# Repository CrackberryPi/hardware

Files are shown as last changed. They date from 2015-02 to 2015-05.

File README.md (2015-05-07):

# Crackberry Pi hardware

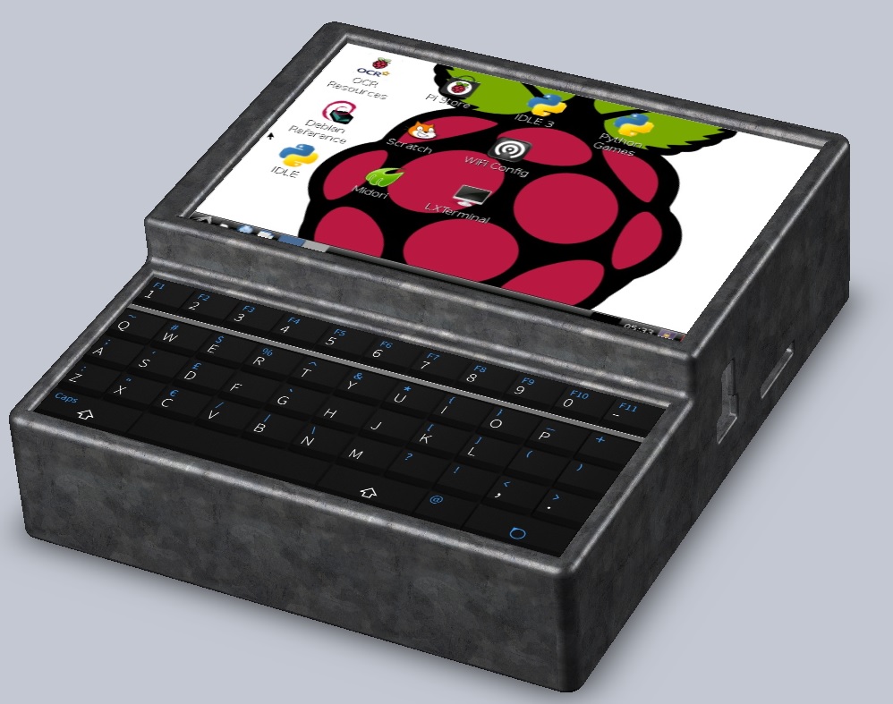
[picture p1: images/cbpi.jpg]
render terrible render


## The plan

The idea is to develop a complete and usable handheld system based on the Raspberry Pi. For this purpose we plan to create a PCB that will provide a small touch screen, a tiny keyboard and some other features. Together with a custom enclosure and a Lithium Ion battery this would form a complete handheld system.

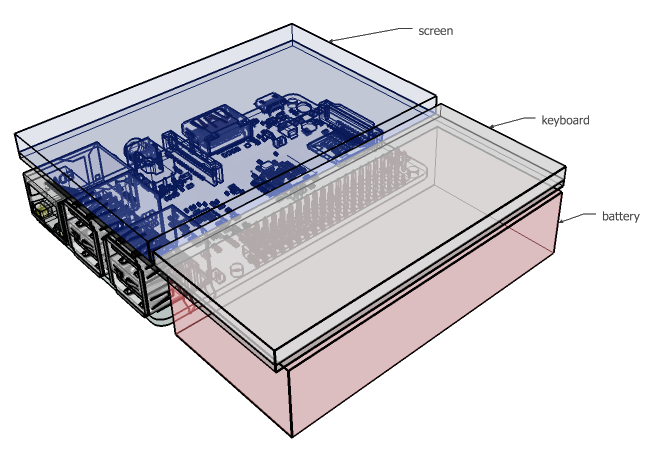
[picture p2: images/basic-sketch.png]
basic sketch


## Progress

####Up and running:

RTC -- [code](http://www.100randomtasks.com/raspberry-pi-rtc)

Random generator -- Lots of noise, lots of 1s and 0s

IR RX -- Using LIRC able to record IR

####Tested but does not work:

Screen -- some wiring issues

Touch controller -- does not show up in i2cdetect

IR TX

####Not yet tested

Keyboard controller

FM

Battery power and charging

EEPROM

## Hardware functionality

### Screen

3.5" 480x320 resistive touch screen. A number of parties sell boards to interface such screens to the Rasberry Pi already. The screens are generally more or less exactly the same size as the Raspberry Pi.

The preliminary candidate is the [CFAF320480C4-035T-TS](https://www.crystalfontz.com/product/CFAF320480C4035TTS#pcn).

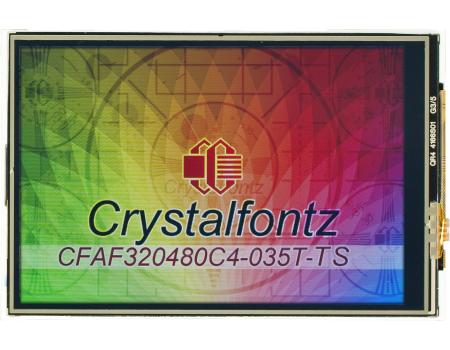
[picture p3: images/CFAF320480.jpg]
touchscreen TFT


The screen has an integrated Himax HX8357-B microcontroller. It is capable of handling DPI, MIPI and SPI interfaces. The latter we will use, connected directly to the RPi headers.

The resistive touchscreen requires an additional driver IC, for which we will use the [TSC2007](http://www.ti.com/lit/an/slaa364/slaa364.pdf), which runs on I2C leaving the entire SPI bus for the screen.

LED backlight can be dimmed using pulse width modulation.

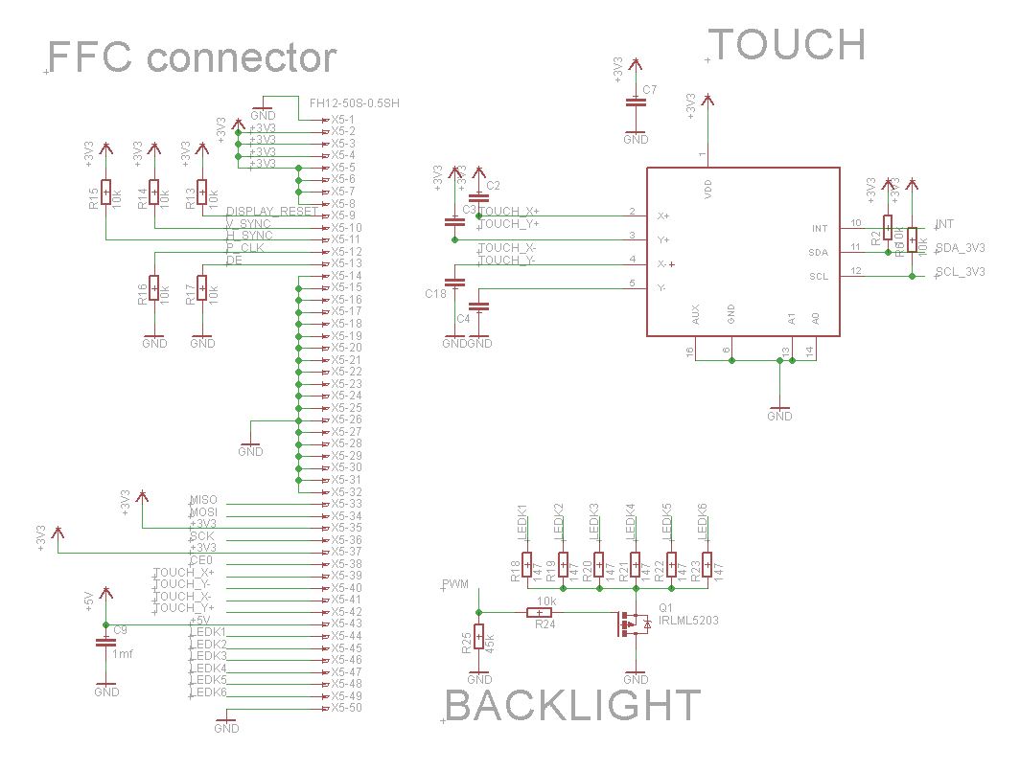
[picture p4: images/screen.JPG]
screen circuitry


The screen's reset pin is wired to GPIO6. This pin should be pulsed low after bootup and then be kept high for normal operation.

The chip select pin CE0 is wired to GPIO8.
```
Chip select input
Low:
 Controller chip is selected. Communications with host is possible.
High:
 Controller chip is not selected. Host interface signals are ignored by the controller.
```

### Keyboard

Looks like we'll go for the same technology (and designer :) ) as [TOHKBD](https://www.kickstarter.com/projects/2028347278/tohkbd-the-other-half-keyboard-for-your-jolla), with the difference that the Crackberry Pi's keyboard will be narrower. The following is a preliminary key layout:

```
         !     @     #     $     %     ^     &     *     (     )     Del
  ESC   1     2     3     4     5     6     7     8     9     0     BS

         F11   F12   {     }     [     ]     _     -     +     =
  TAB     Q     W     E     R     T     Y     U     I     O     P     CR

                                         ;     :     '     " 
  Caps      A     S     D     F     G     H     J     K     L     CR  CR

             ~     `                       <     >     ? ,   PgUp  Ins \
  Shift       Z     X     C     V     B     N     M     .     Up    /

                                                       Home  PgDn  End
  Sym   Ctrl  Alt              Spacebar                 Left  Down  Right
```

This keyboard is a combination of a metal frame, a silicon mat, plastic keys and a dome-sticker. Here's a picture:

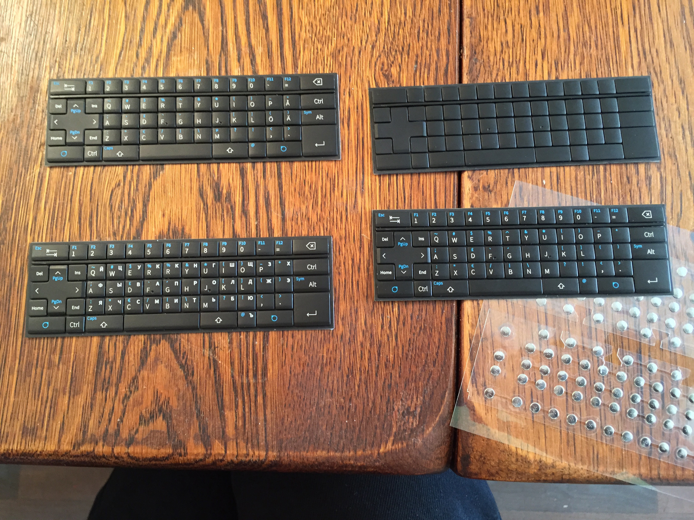
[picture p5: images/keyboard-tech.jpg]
keyboard tech keyboard-tech


The keyboard is controlled by the TCA8424

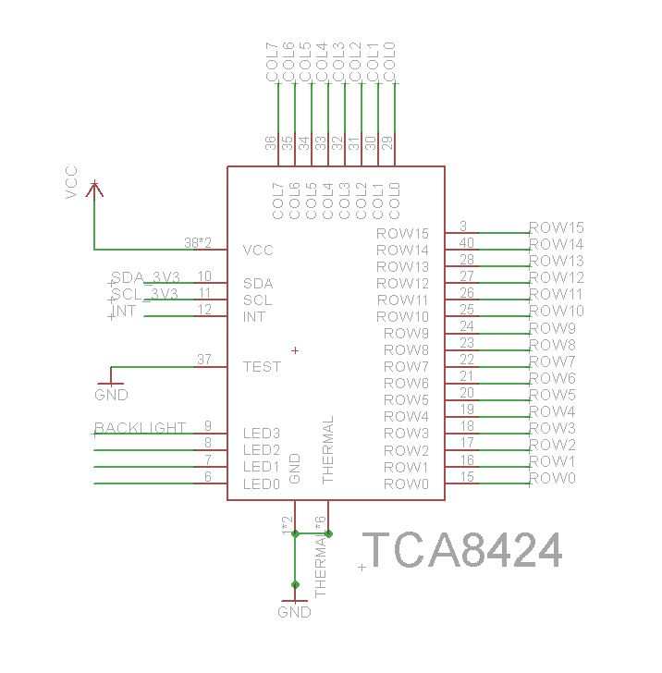
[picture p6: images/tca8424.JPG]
TCA8424 keyboard controller


### Real Time Clock

Our circuit provide a Real Time Clock (RTC) to the Raspberry Pi. Plenty of ICs that do this. Will probably need its own miniature battery of some sort.

RTC ic: [MCP7940N](http://nl.mouser.com/Search/ProductDetail.aspx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)

Crystal: [CM200C](http://nl.mouser.com/ProductDetail/Citizen-Finetech-Miyota/CM200C-32768KDZB-UT/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)

Battery holder: [CR1216](http://nl.mouser.com/ProductDetail/Linx-Technologies/BAT-HLD-012-SMT/?qs=sGAEpiMZZMtbbFRYSpBbWwy2JjMrRsgr)

Header: [20x2 8.5mm](http://www.tme.eu/en/details/zl262-40dg/pin-headers/zl262-40dg#)

Display connector: [ZIF 50](http://www.digikey.com/product-detail/en/62684-501100ALF/609-1197-2-ND/1001511)

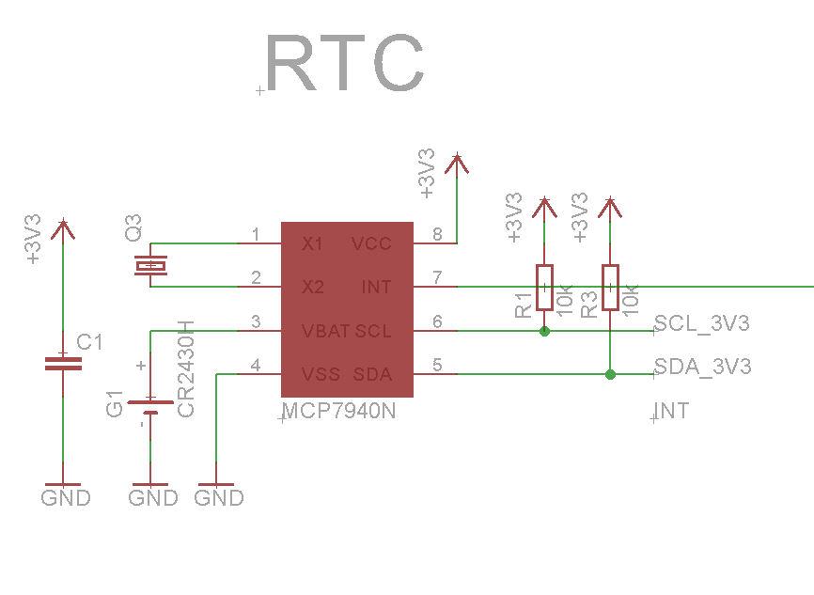
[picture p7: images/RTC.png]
rtc circuit


[RTC setup](http://tom.meinlschmidt.org/2014/02/19/mcp7940-rtc-with-pi/)

### Hardware random circuit

Serious cryptographic applications on embedded hardware invariably suffer from a lack of proper sources of random entropy. We're not simply trusting the Pi SoC chip for this, but we're providing an additional noise with two NPN transistors:

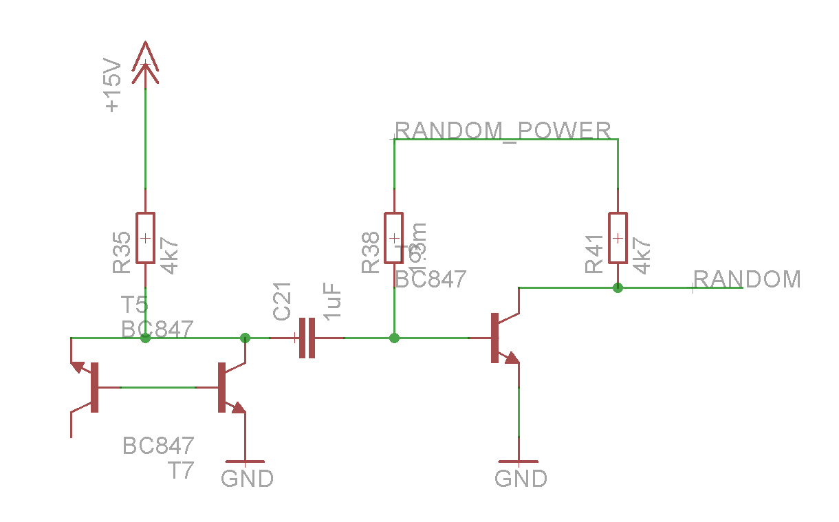
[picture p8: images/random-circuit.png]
random circuit


This needs to be powered by an 18V stepup circuit, powered by a NCP1406:

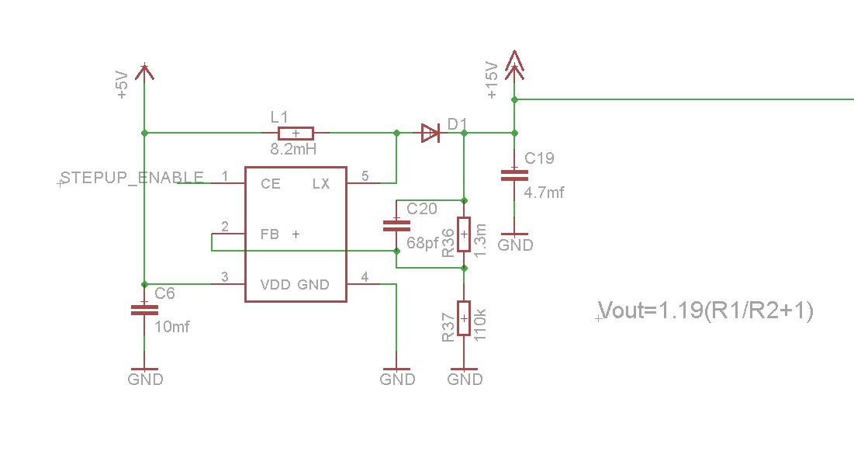
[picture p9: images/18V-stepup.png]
18V stepup


Quiescent current of circuit needs to investigated and if significant the Pi should be able to turn this on and off as random entropy will only be needed at boot time.

### Power, Lithium Ion Battery and charging circuit

Our system should optimally include a hardware on/off switch so that even security-conscious users can be certain the system is actually off when they think it is off.

This means adding an extra micro-usb port on our PCB, which is intended for charging the battery. The RPi will in turn be powered through the appropriate pin on the connector, with a switch in between. This allows the battery to charge while all other components are turned off.

Current best battery we can find is [this one](https://www.adafruit.com/products/354) from Adafruit, which fits rather perfectly and at 3.7V * 4.4 Ah would give us 16.28 Wh which at 5W gives us somewhat over 3 hrs of operation.

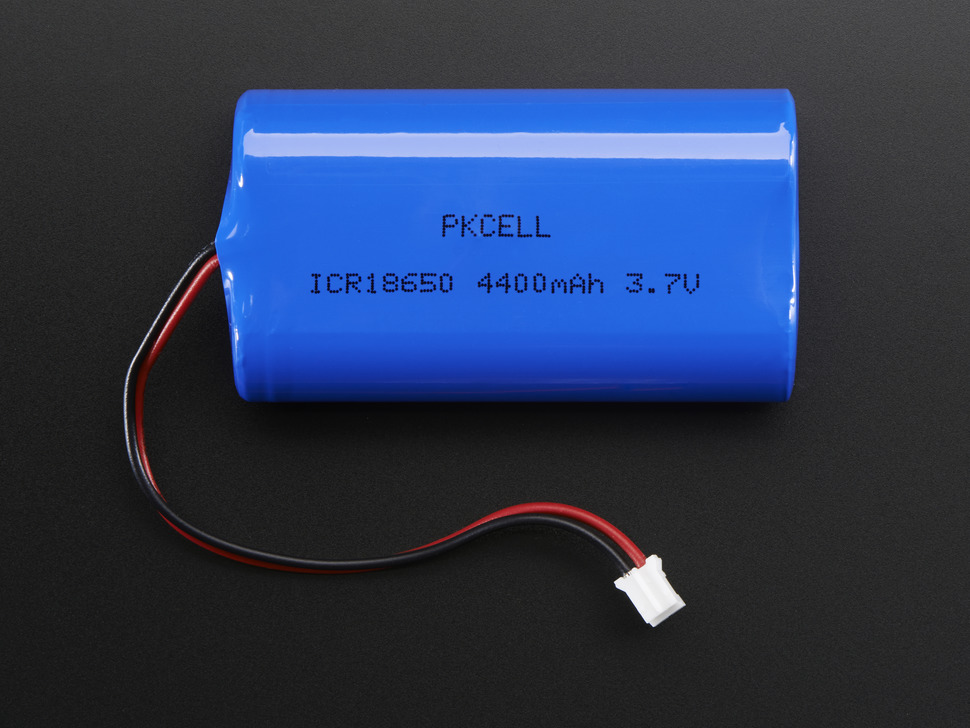
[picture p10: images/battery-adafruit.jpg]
Battery battery


For the charging circuit we will use the BQ24297. This charging IC uses USB input power to charge the battery, has a step-up circuit supplying 5V@1.5A and a complete powerpath management for switching between battery usage and usb input with charging.

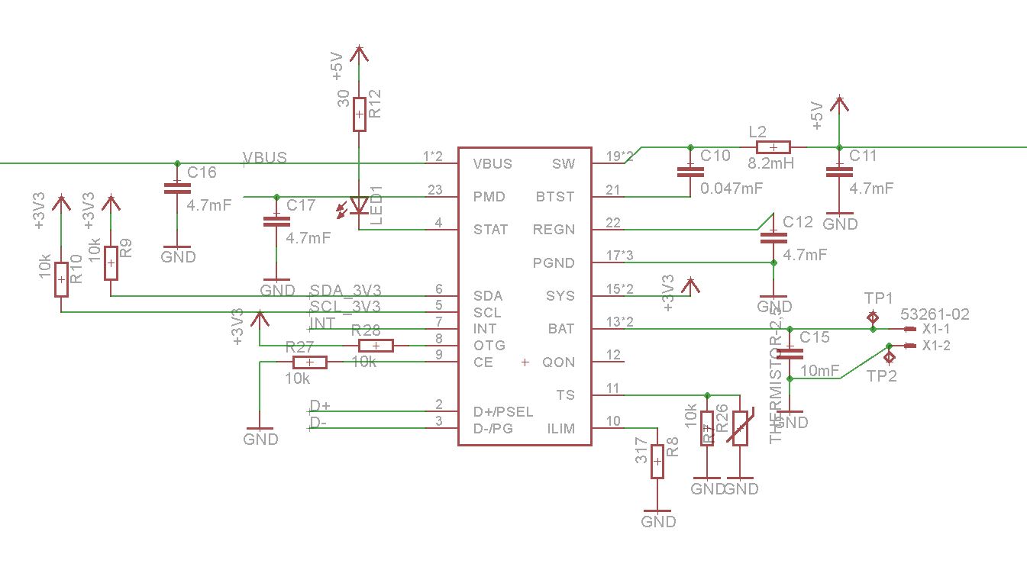
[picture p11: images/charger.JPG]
Charging circuit charging circuit


### FM transmitter

A [Si4713](http://nl.mouser.com/ProductDetail/Silicon-Labs/Si4713-B30-GM/?qs=sGAEpiMZZMvRDq0TKoyiQrUxOY0c9SY0) controlled over I2C steals the audio from the top of the 3.5jack. An antenna wire needs to be soldered on the PCB to transfer the signal.

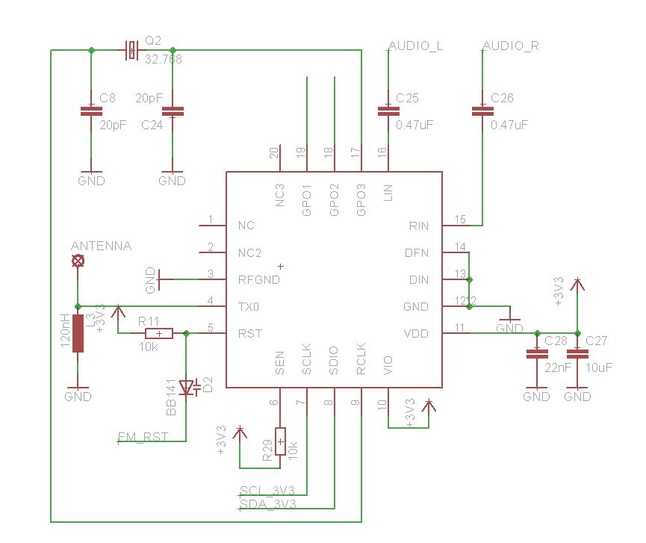
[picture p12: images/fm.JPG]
FM transmitter transmitter


### IR rx/tx

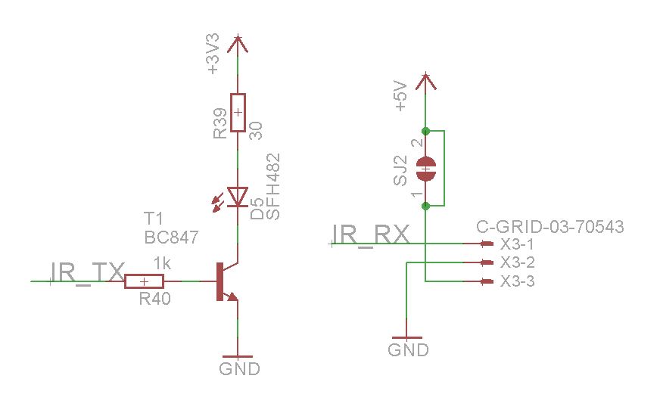
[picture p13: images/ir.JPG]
IR infrared rx/tx


### HAT standard

[HAT](http://www.raspberrypi.org/introducing-raspberry-pi-hats/)s are Raspberry Pi expansion boards that conform to the [standard](https://github.com/raspberrypi/hats) set by the Raspberry Pi foundation. This involves a small I2C EEPROM filled with manufacturer information as well as size constraints (which we will not meet if we include a keyboard). We should nevertheless try to comply with this standard to the extent possible. This will also cause the Pi bootloader and standard software distributions to know about our GPIO pins, meaning less chance to break something.

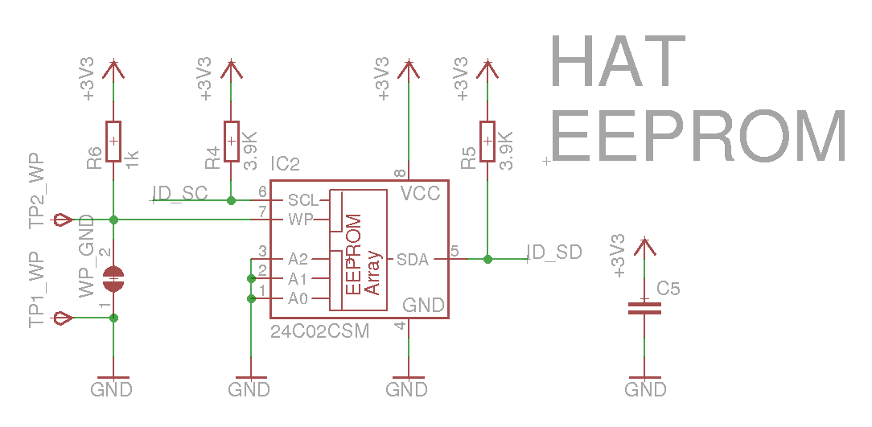
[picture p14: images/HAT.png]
EEPROM


This needs to be a CAT24C32 (32kbit, 4kbyte, same package and pin-out). By default the EEPROM is write-protected. By soldering the solder-jumper of shorting the testpads the write-protect is disabled. This will reduce the risk of accidental EEPROM resetting and breaking HAT-'compliance', but still give full freedom to the user.

Check [here](https://github.com/raspberrypi/hats/blob/master/eeprom-format.md) for further details on EEPROM programming.

### RPi GPIO usage

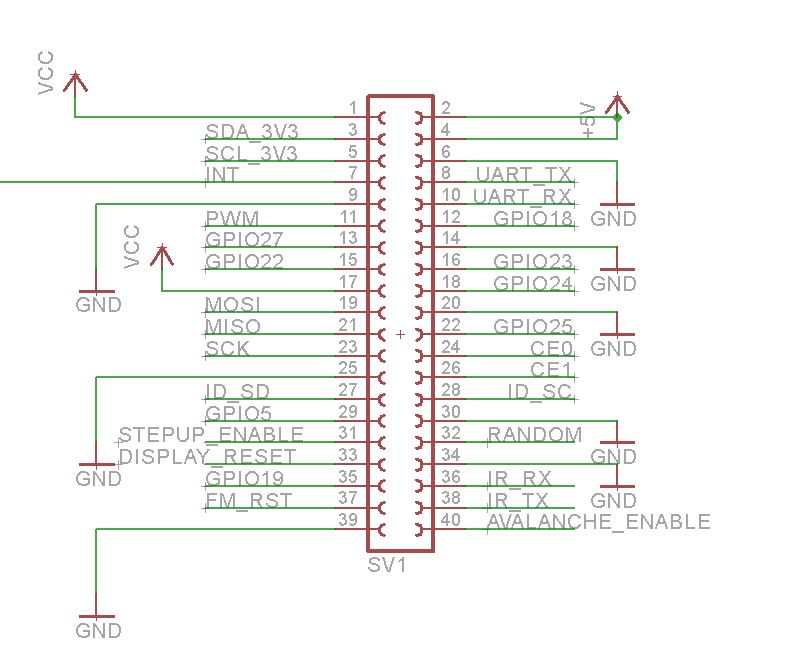
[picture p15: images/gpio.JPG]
gpio


### Extended header

Additionally to the functionality inside, the possibility to still fiddle around will be kept intact by extending 18 pins on a [2x9 male header](http://nl.mouser.com/ProductDetail/Molex/87760-1816/?qs=sGAEpiMZZMs%252bGHln7q6pmzi5lyGzg2V24XJVwyxGDq0%3d) to the side. 

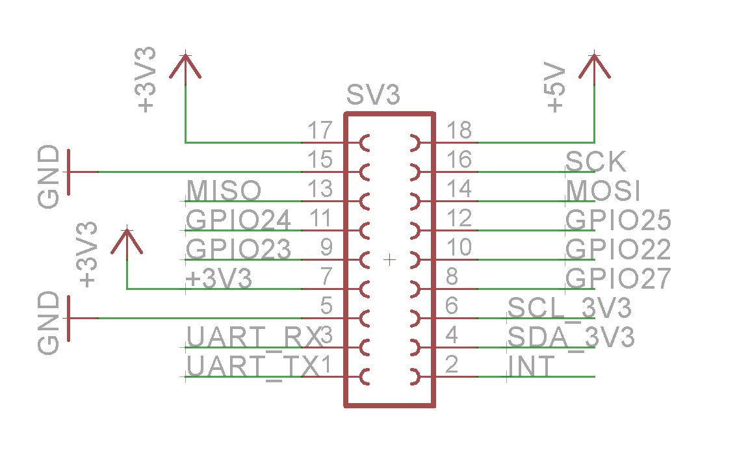
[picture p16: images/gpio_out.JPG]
gpio out


## License 

All development documentation, CAD drawings, driver source code that we develop ourselves is licensed under a <a rel="license" href="http://creativecommons.org/licenses/by-nc-sa/4.0/">Creative Commons Attribution-NonCommercial-ShareAlike 4.0 International License</a> unless specified otherwise. Please talk to us is you have commercial plans with any of this: we'll probably work something out.



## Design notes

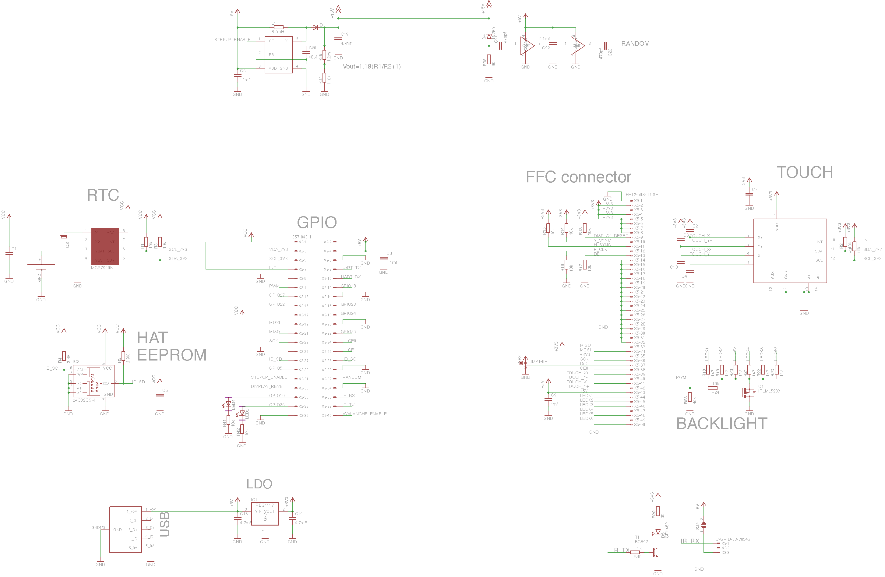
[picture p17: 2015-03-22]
Eagle/CrackberryPi-schematic.png

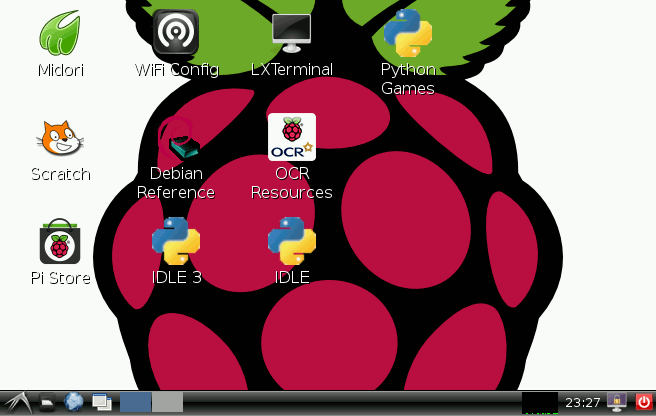
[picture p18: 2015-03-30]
images/raspbian.png

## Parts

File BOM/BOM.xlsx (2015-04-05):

 | Description | Product code | Amount | unit price
 |  |  |  | 1 | 10 | 20 | 25 | 50 | 100 | 200 | 250 | 500 | 1000 | 2000
 | Screen | CFAF320480C4 | 1 | 30.71 | 29.82 | 26.98 | 26.98 | 24.74 | 22.3 | 20.44 | 20.44 | 17.46 | 13.04 | 13.04 | 13.04
 | Touch controller | TSC2007 | 1 | 3.72 | 3 | 3 | 3 | 3 | 2.72 | 2.72 | 2.46 | 1.99 | 1.86 | 1.86 | 1.86
 | Zif connector | FCI 62684-502100ALF | 1 | 1.35 | 1.191 | 1.191 | 1.1208 | 1.074 | 1.0273 | 1.0273 | 0.93392 | 0.84052 | 0.74712 | 0.63675 | 0.63675
 | Backlight Mosfet | IRLML5203 | 1 | 0.507 | 0.211 | 0.211 | 0.211 | 0.211 | 0.155 | 0.155 | 0.155 | 0.155 | 0.145 | 0.145 | 0.145
 | Header | ZL262-40DG | 1 | 0.3664 | 0.2664 | 0.2664 | 0.2664 | 0.1818 | 0.1818 | 0.1818 | 0.1818 | 0.1445 | 0.1309 | 0.1309 | 0.1309
 | RTC | 579-MCP7940N-I/SN | 1 | 0.805 | 0.67 | 0.67 | 0.615 | 0.615 | 0.595 | 0.595 | 0.595 | 0.595 | 0.595 | 0.595 | 0.595
 | RTC crystal | 695-CM200C-327K-U | 2 | 0.471 | 0.407 | 0.407 | 0.407 | 0.304 | 0.254 | 0.254 | 0.254 | 0.223 | 0.19 | 0.19 | 0.38
 | Battery holder | BAT-HLD-012-SMT | 1 | 0.265 | 0.265 | 0.265 | 0.243 | 0.243 | 0.221 | 0.221 | 0.221 | 0.201 | 0.181 | 0.181 | 0.181
 | EEPROM | 698-CAT24C32WI-G | 1 | 0.511 | 0.376 | 0.376 | 0.376 | 0.376 | 0.237 | 0.237 | 0.237 | 0.237 | 0.183 | 0.183 | 0.183
 | Charger | 595-BQ24297RGET | 1 | 5.1 | 4.56 | 4.56 | 4.1 | 3.92 | 3.74 | 3.74 | 3.38 | 3.02 | 2.33 | 2.03 | 2.03
 | LDO | 621-AP1117IE33G-13 | 1 | 3.79 | 0.257 | 0.257 | 0.257 | 0.257 | 0.143 | 0.143 | 0.143 | 0.143 | 0.107 | 0.09 | 0.09
 | Battery connector |  | 1 | 0.53 | 0.495 | 0.495 | 0.4456 | 0.3962 | 0.3797 | 0.3797 | 0.34668 | 0.33018 | 0.24763 | 0.24013 | 0.24013
 | LED |  | 1 | 0.072 | 0.069 | 0.069 | 0.069 | 0.069 | 0.063 | 0.063 | 0.057 | 0.051 | 0.049 | 0.048 | 0.048
 | USB | 649-10118192-0001LF | 1 | 0.416 | 0.286 | 0.286 | 0.286 | 0.286 | 0.247 | 0.247 | 0.247 | 0.235 | 0.178 | 0.163 | 0.163
 | Mosfet | 821-BC847B | 1 | 0.114 | 0.099 | 0.099 | 0.099 | 0.099 | 0.035 | 0.035 | 0.035 | 0.035 | 0.02 | 0.018 | 0.018
 | IR transmitter | 859-LTE-302-M | 1 | 0.208 | 0.189 | 0.189 | 0.189 | 0.174 | 0.152 | 0.152 | 0.152 | 0.133 | 0.125 | 0.117 | 0.117
 | IR receiver | 782-TSOP38238 | 1 | 0.606 | 0.606 | 0.606 | 0.562 | 0.513 | 0.464 | 0.464 | 0.464 | 0.44 | 0.415 | 0.367 | 0.367
 | Keyboard driver | 595-TCA8424RHAR | 1 | 2.08 | 1.87 | 1.87 | 1.63 | 1.53 | 1.51 | 1.51 | 1.34 | 1.14 | 0.832 | 0.832 | 0.832
 | Side header | DS1065-14-2*9S8BR | 1 | 1.02 | 0.95 | 0.95 | 0.85 | 0.85 | 0.75 | 0.75 | 0.75 | 0.61 | 0.61 | 0.61 | 0.61
 | FM | 634-SI4713-B30-GM | 1 | 12.08 | 12.08 | 12.08 | 11.67 | 11.67 | 11.25 | 11.25 | 11.25 | 11.25 | 4.01 | 2.43 | 2.43
 | EMI filter | 81-BLM11B141S | 1 | 0.1 | 0.064 | 0.064 | 0.064 | 0.064 | 0.032 | 0.032 | 0.032 | 0.032 | 0.027 | 0.027 | 0.027
 | Pogo | 581-709150001050006 | 3 | 1.56 | 1.56 | 1.56 | 1.56 | 1.56 | 1.3 | 1.18 | 1.18 | 1.04 | 0.923 | 0.868 | 2.604
 | Stepup | 863-NCP1406SNT1G | 1 | 0.758 | 0.587 | 0.587 | 0.587 | 0.587 | 0.379 | 0.379 | 0.379 | 0.379 | 0.303 | 0.256 | 0.256
 | Diode | 78-BAT54WS-E3-18 | 1 | 0.054 | 0.045 | 0.045 | 0.045 | 0.045 | 0.036 | 0.036 | 0.034 | 0.033 | 0.033 | 0.033 | 0.033
 | Avalanch Diode | 78-BZX384C12-VGS18 | 1 | 0.045 | 0.045 | 0.045 | 0.045 | 0.04 | 0.04 | 0.04 | 0.04 | 0.03 | 0.03 | 0.03 | 0.03
 | Amp | MAX2650EUS+T | 2 | 1.46 | 1.46 | 1.46 | 1.33 | 1.25 | 0.994 | 0.994 | 0.985 | 0.928 | 0.805 | 0.805 | 1.61
RLC
 | R 1.3M |  | 1 | 0.01 | 0.01 | 0.01 | 0.01 | 0.01 | 0.01 | 0.01 | 0.01 | 0.01 | 0.01 | 0.01
 | R 45K |  | 1 | 0.01 | 0.01 | 0.01 | 0.01 | 0.01 | 0.01 | 0.01 | 0.01 | 0.01 | 0.01 | 0.01
 | R 110K |  | 1 | 0.01 | 0.01 | 0.01 | 0.01 | 0.01 | 0.01 | 0.01 | 0.01 | 0.01 | 0.01 | 0.01
 | R 10K |  | 17 | 0.01 | 0.01 | 0.01 | 0.01 | 0.01 | 0.01 | 0.01 | 0.01 | 0.01 | 0.01 | 0.01
 | R 3.9K |  | 2 | 0.01 | 0.01 | 0.01 | 0.01 | 0.01 | 0.01 | 0.01 | 0.01 | 0.01 | 0.01 | 0.01
 | R 1K |  | 1 | 0.01 | 0.01 | 0.01 | 0.01 | 0.01 | 0.01 | 0.01 | 0.01 | 0.01 | 0.01 | 0.01
 | R 317 |  | 1 | 0.01 | 0.01 | 0.01 | 0.01 | 0.01 | 0.01 | 0.01 | 0.01 | 0.01 | 0.01 | 0.01
 | R 30 |  | 3 | 0.01 | 0.01 | 0.01 | 0.01 | 0.01 | 0.01 | 0.01 | 0.01 | 0.01 | 0.01 | 0.01
 | R 147 |  | 6 | 0.01 | 0.01 | 0.01 | 0.01 | 0.01 | 0.01 | 0.01 | 0.01 | 0.01 | 0.01 | 0.01
 | T thermistor |  | 1 | 0.01 | 0.01 | 0.01 | 0.01 | 0.01 | 0.01 | 0.01 | 0.01 | 0.01 | 0.01 | 0.01
 | C 10uF |  | 3 | 0.01 | 0.01 | 0.01 | 0.01 | 0.01 | 0.01 | 0.01 | 0.01 | 0.01 | 0.01 | 0.01
 | C 4.7uF |  | 7 | 0.01 | 0.01 | 0.01 | 0.01 | 0.01 | 0.01 | 0.01 | 0.01 | 0.01 | 0.01 | 0.01
 | C 1uF |  | 1 | 0.01 | 0.01 | 0.01 | 0.01 | 0.01 | 0.01 | 0.01 | 0.01 | 0.01 | 0.01 | 0.01
 | C 0.47uF |  | 3 | 0.01 | 0.01 | 0.01 | 0.01 | 0.01 | 0.01 | 0.01 | 0.01 | 0.01 | 0.01 | 0.01
 | C 0.1uF |  | 8 | 0.01 | 0.01 | 0.01 | 0.01 | 0.01 | 0.01 | 0.01 | 0.01 | 0.01 | 0.01 | 0.01
 | C 22nF |  | 1 | 0.01 | 0.01 | 0.01 | 0.01 | 0.01 | 0.01 | 0.01 | 0.01 | 0.01 | 0.01 | 0.01
 | C 68pF |  | 1 | 0.01 | 0.01 | 0.01 | 0.01 | 0.01 | 0.01 | 0.01 | 0.01 | 0.01 | 0.01 | 0.01
 | C 470pF |  | 2 | 0.01 | 0.01 | 0.01 | 0.01 | 0.01 | 0.01 | 0.01 | 0.01 | 0.01 | 0.01 | 0.01
 | C 20pF |  | 2 | 0.01 | 0.01 | 0.01 | 0.01 | 0.01 | 0.01 | 0.01 | 0.01 | 0.01 | 0.01 | 0.01
 | L 8.2mH |  | 2 | 0.01 | 0.01 | 0.01 | 0.01 | 0.01 | 0.01 | 0.01 | 0.01 | 0.01 | 0.01 | 0.01
 | L 120nH |  | 1 | 0.01 | 0.01 | 0.01 | 0.01 | 0.01 | 0.01 | 0.01 | 0.01 | 0.01 | 0.01 | 0.01
 | Battery | 4400mah | 1 | 4.1 | 4.1 | 4.1 | 4.1 | 4.1 | 4.1 | 4.1 | 4.1 | 4.1 | 4.1 | 4.1 | 4.1
 | PCB | itead | 1 | 1.5 | 1.5 | 1.5 | 1.5 | 1.5 | 1.5 | 1.5 | 1.5 | 1.5 | 1.5 | 1.5 | 1.5
 | Domesheet | china | 1 | 2 | 2 | 2 | 2 | 2 | 2 | 2 | 2 | 2 | 2 | 2 | 2
 | Keypad | china | 1 | 6 | 6 | 6 | 6 | 6 | 6 | 6 | 6 | 6 | 6 | 6 | 6
 | Casing | shapeways | 1 | 16.18 | 16.18 | 16.18 | 16.18 | 16.18 | 16.18 | 16.18 | 16.18 | 16.18 | 16.18 | 16.18 | 16.18
 | Assembly | estland | 1 | 11 | 11 | 11 | 11 | 11 | 11 | 11 | 11 | 11 | 11 | 11 | 11
 | Final assembly | NL | 1 | 5 | 5 | 5 | 5 | 5 | 5 | 5 | 5 | 5 | 5 | 5
 |  | SMD | 1 | 74.40 | 67.07 | 64.23 | 62.51 | 59.38 | 53.70 | 51.48 | 50.54 | 45.56 | 31.61 | 29.31
 |  | Other HW | 1 | 29.78 | 29.78 | 29.78 | 29.78 | 29.78 | 29.78 | 29.78 | 29.78 | 29.78 | 29.78 | 29.78
 |  | Assembly | 1 | 16.00 | 16.00 | 16.00 | 16.00 | 16.00 | 16.00 | 16.00 | 16.00 | 16.00 | 16.00 | 16.00
 |  |  | units | 1 | 10 | 20 | 25 | 50 | 100 | 200 | 250 | 500 | 1000 | 2000
 |  | Total |  | 120.18 | 112.85 | 110.01 | 108.29 | 105.16 | 99.48 | 97.26 | 96.32 | 91.34 | 77.39 | 75.09

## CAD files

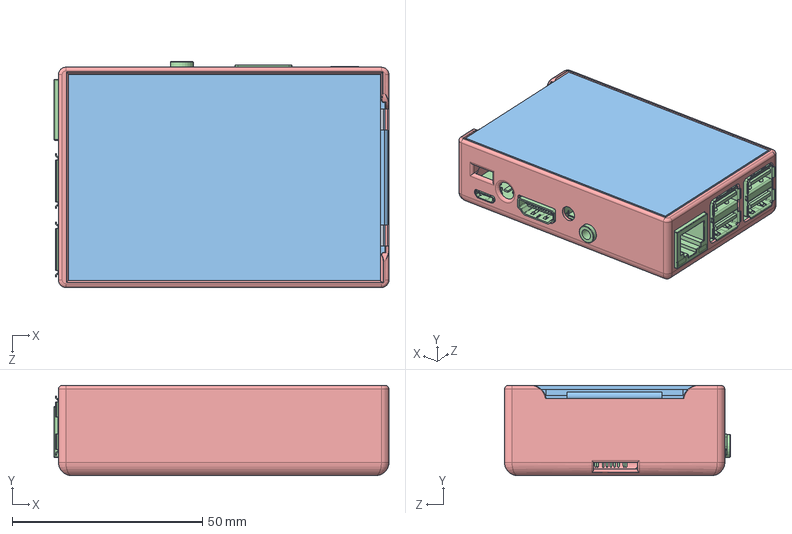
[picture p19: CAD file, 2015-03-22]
CAD/Assembly.SLDASM
88.2 x 23.8 x 59.5 mm
PCB
Header
Display
Raspberry_Pi_Model_B+_3D_Assy_1
Casing

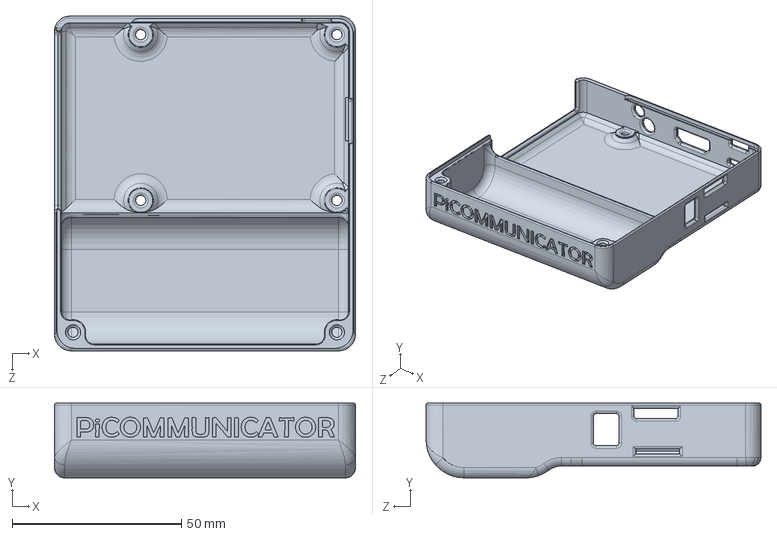
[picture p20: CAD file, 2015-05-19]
CAD/Backup of Casing_1.2.SLDPRT
89.0 x 22.1 x 99.0 mm

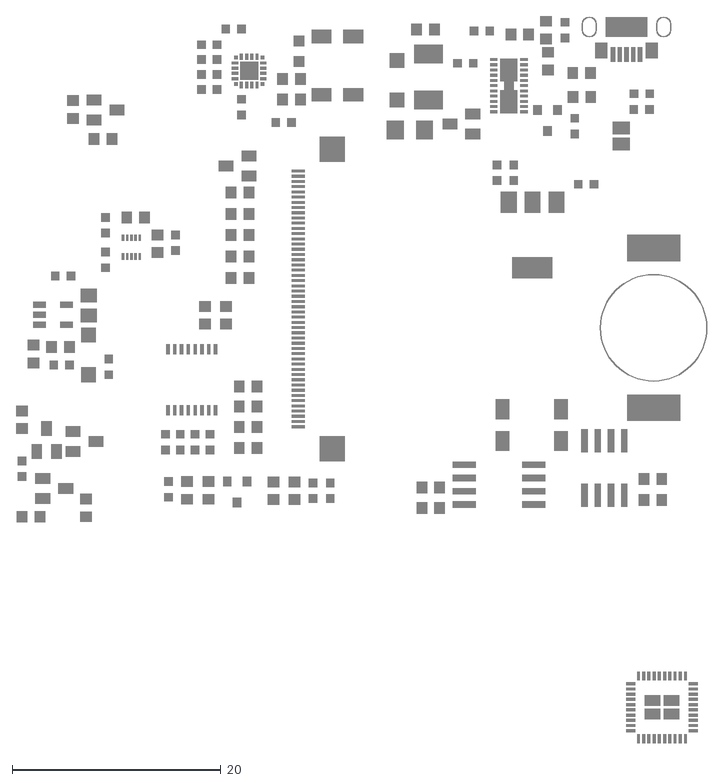
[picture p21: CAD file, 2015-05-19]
Eagle/CrackberryPi_1.0.6.2.dxf
66.2 x 69.6

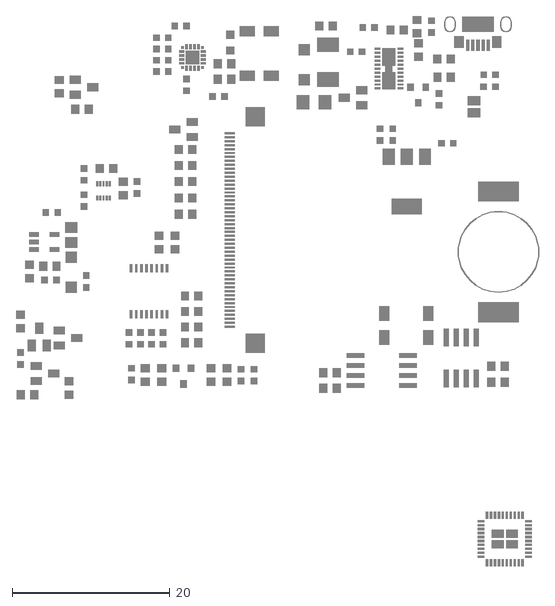
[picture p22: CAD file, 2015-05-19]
Eagle/CrackberryPi_1.0.6.3.dxf
66.2 x 69.6

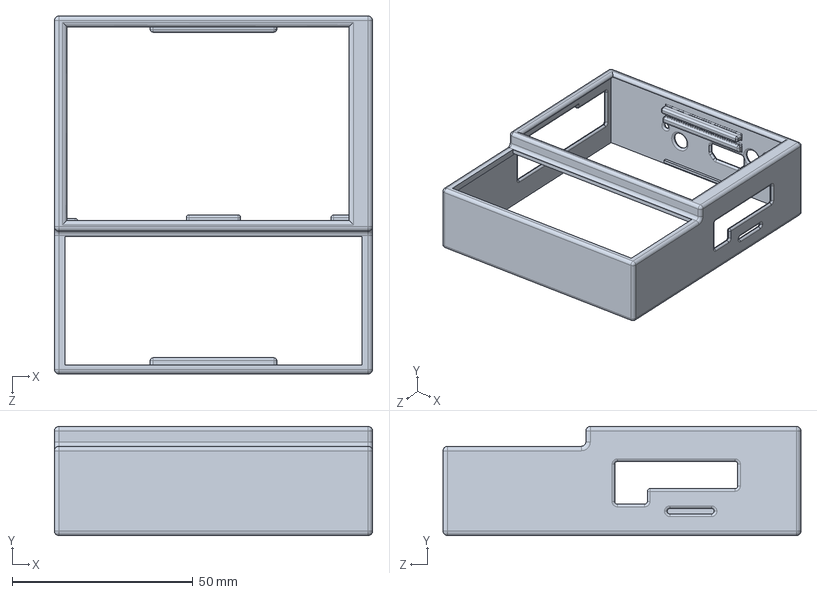
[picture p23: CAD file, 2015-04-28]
CAD/Casing_1.1.1.SLDPRT
88.0 x 30.2 x 99.0 mm

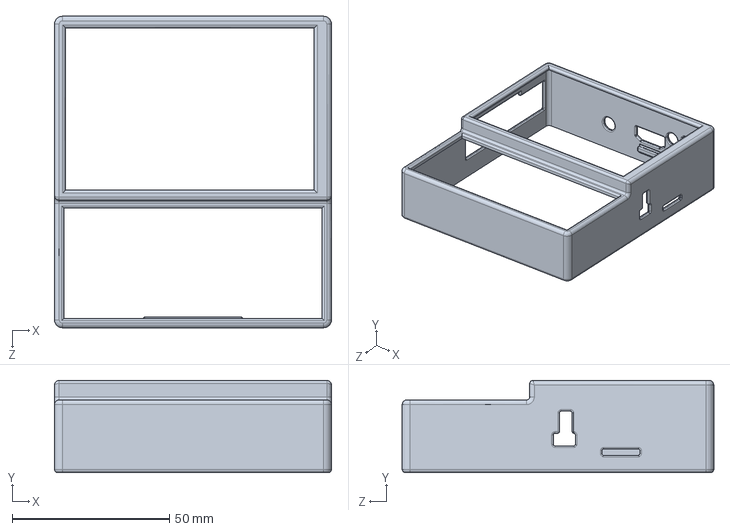
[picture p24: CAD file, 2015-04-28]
CAD/Backup of Casing_1.0.2.SLDPRT
88.0 x 29.3 x 99.0 mm

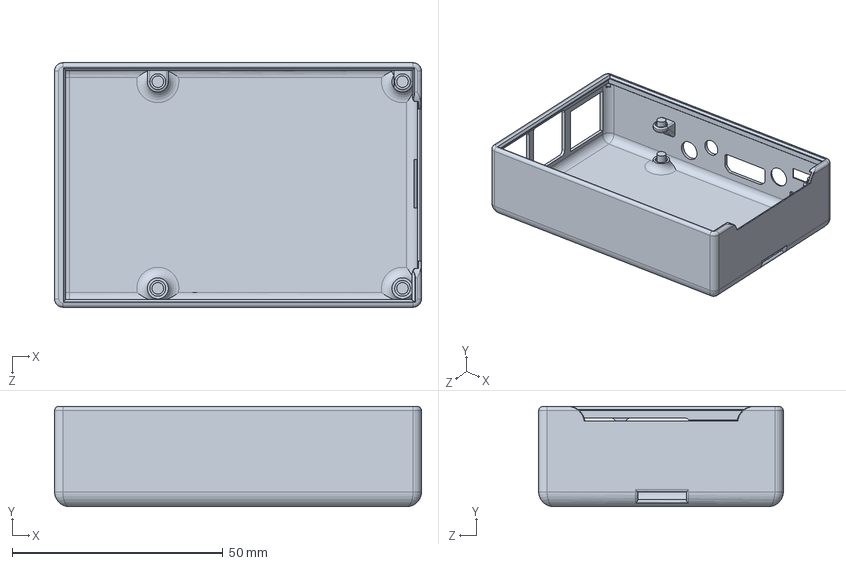
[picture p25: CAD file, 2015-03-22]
CAD/Casing.SLDPRT
87.0 x 23.8 x 58.0 mm

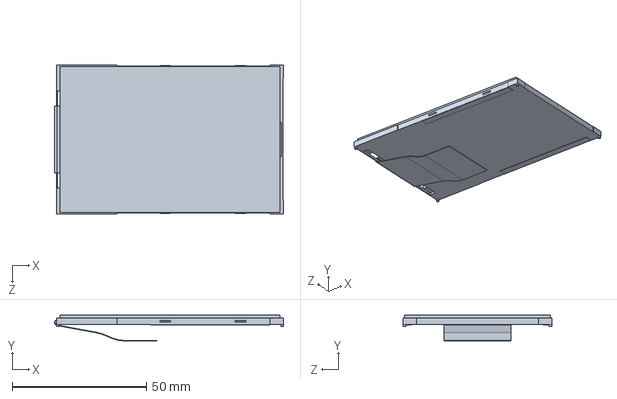
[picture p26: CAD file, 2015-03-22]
CAD/Display.SLDPRT
85.3 x 9.60 x 55.3 mm

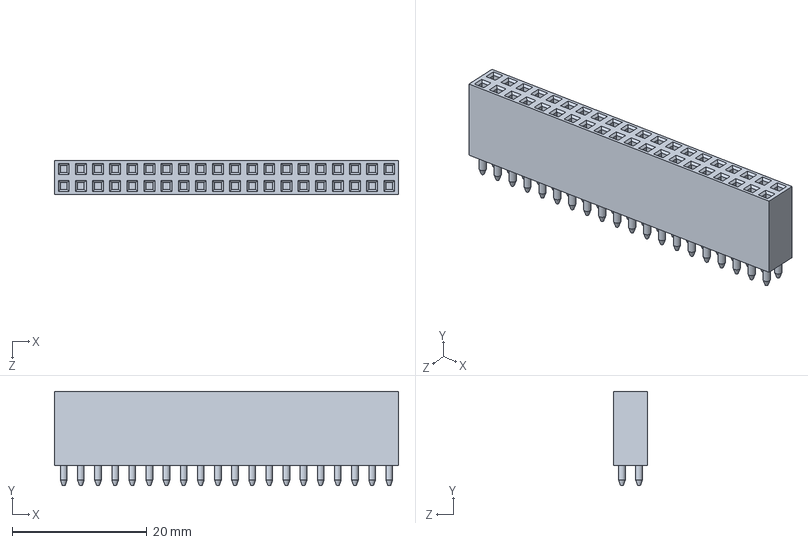
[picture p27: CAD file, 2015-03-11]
CAD/Header.SLDPRT
51.0 x 14.0 x 5.00 mm

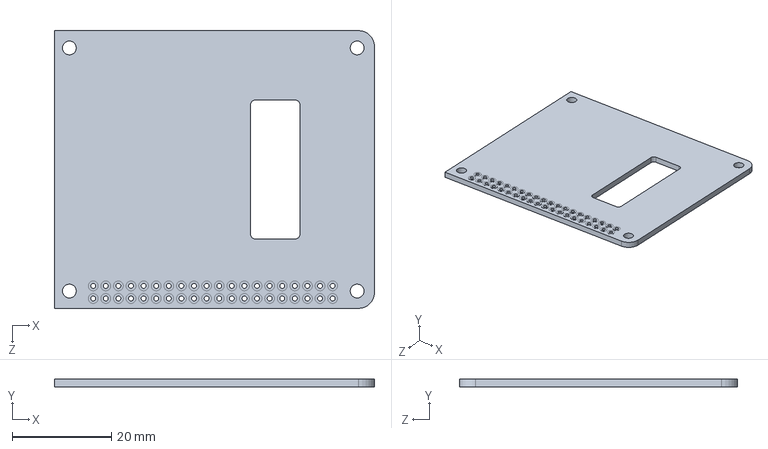
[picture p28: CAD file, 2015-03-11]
CAD/PCB.SLDPRT
64.5 x 1.65 x 56.0 mm

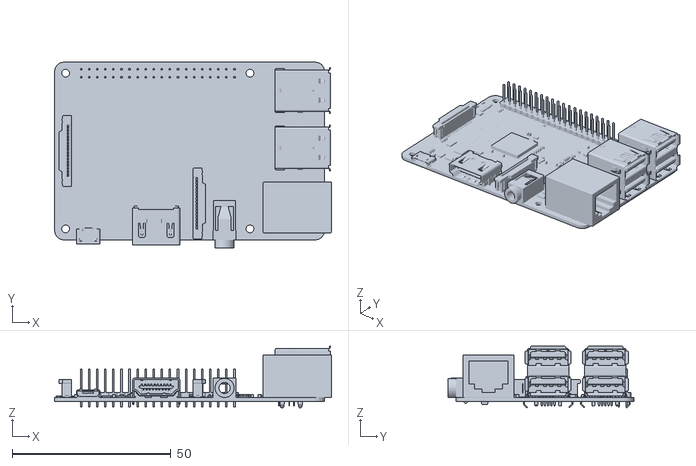
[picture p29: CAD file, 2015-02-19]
CAD/Raspberry_Pi_Model_B+.STL
87.2 x 58.5 x 19.4

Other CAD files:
CAD/Casing_1.2.SLDPRT
CAD/Casing_1.0.2.SLDPRT
CAD/Backup of Casing_1.1.1.SLDPRT
CAD/Casing.STL
CAD/Casing_1.0.2.STL
CAD/Casing_1.1.1.STL
CAD/Casing_1.2.STL
CAD/basic-sketch.skp

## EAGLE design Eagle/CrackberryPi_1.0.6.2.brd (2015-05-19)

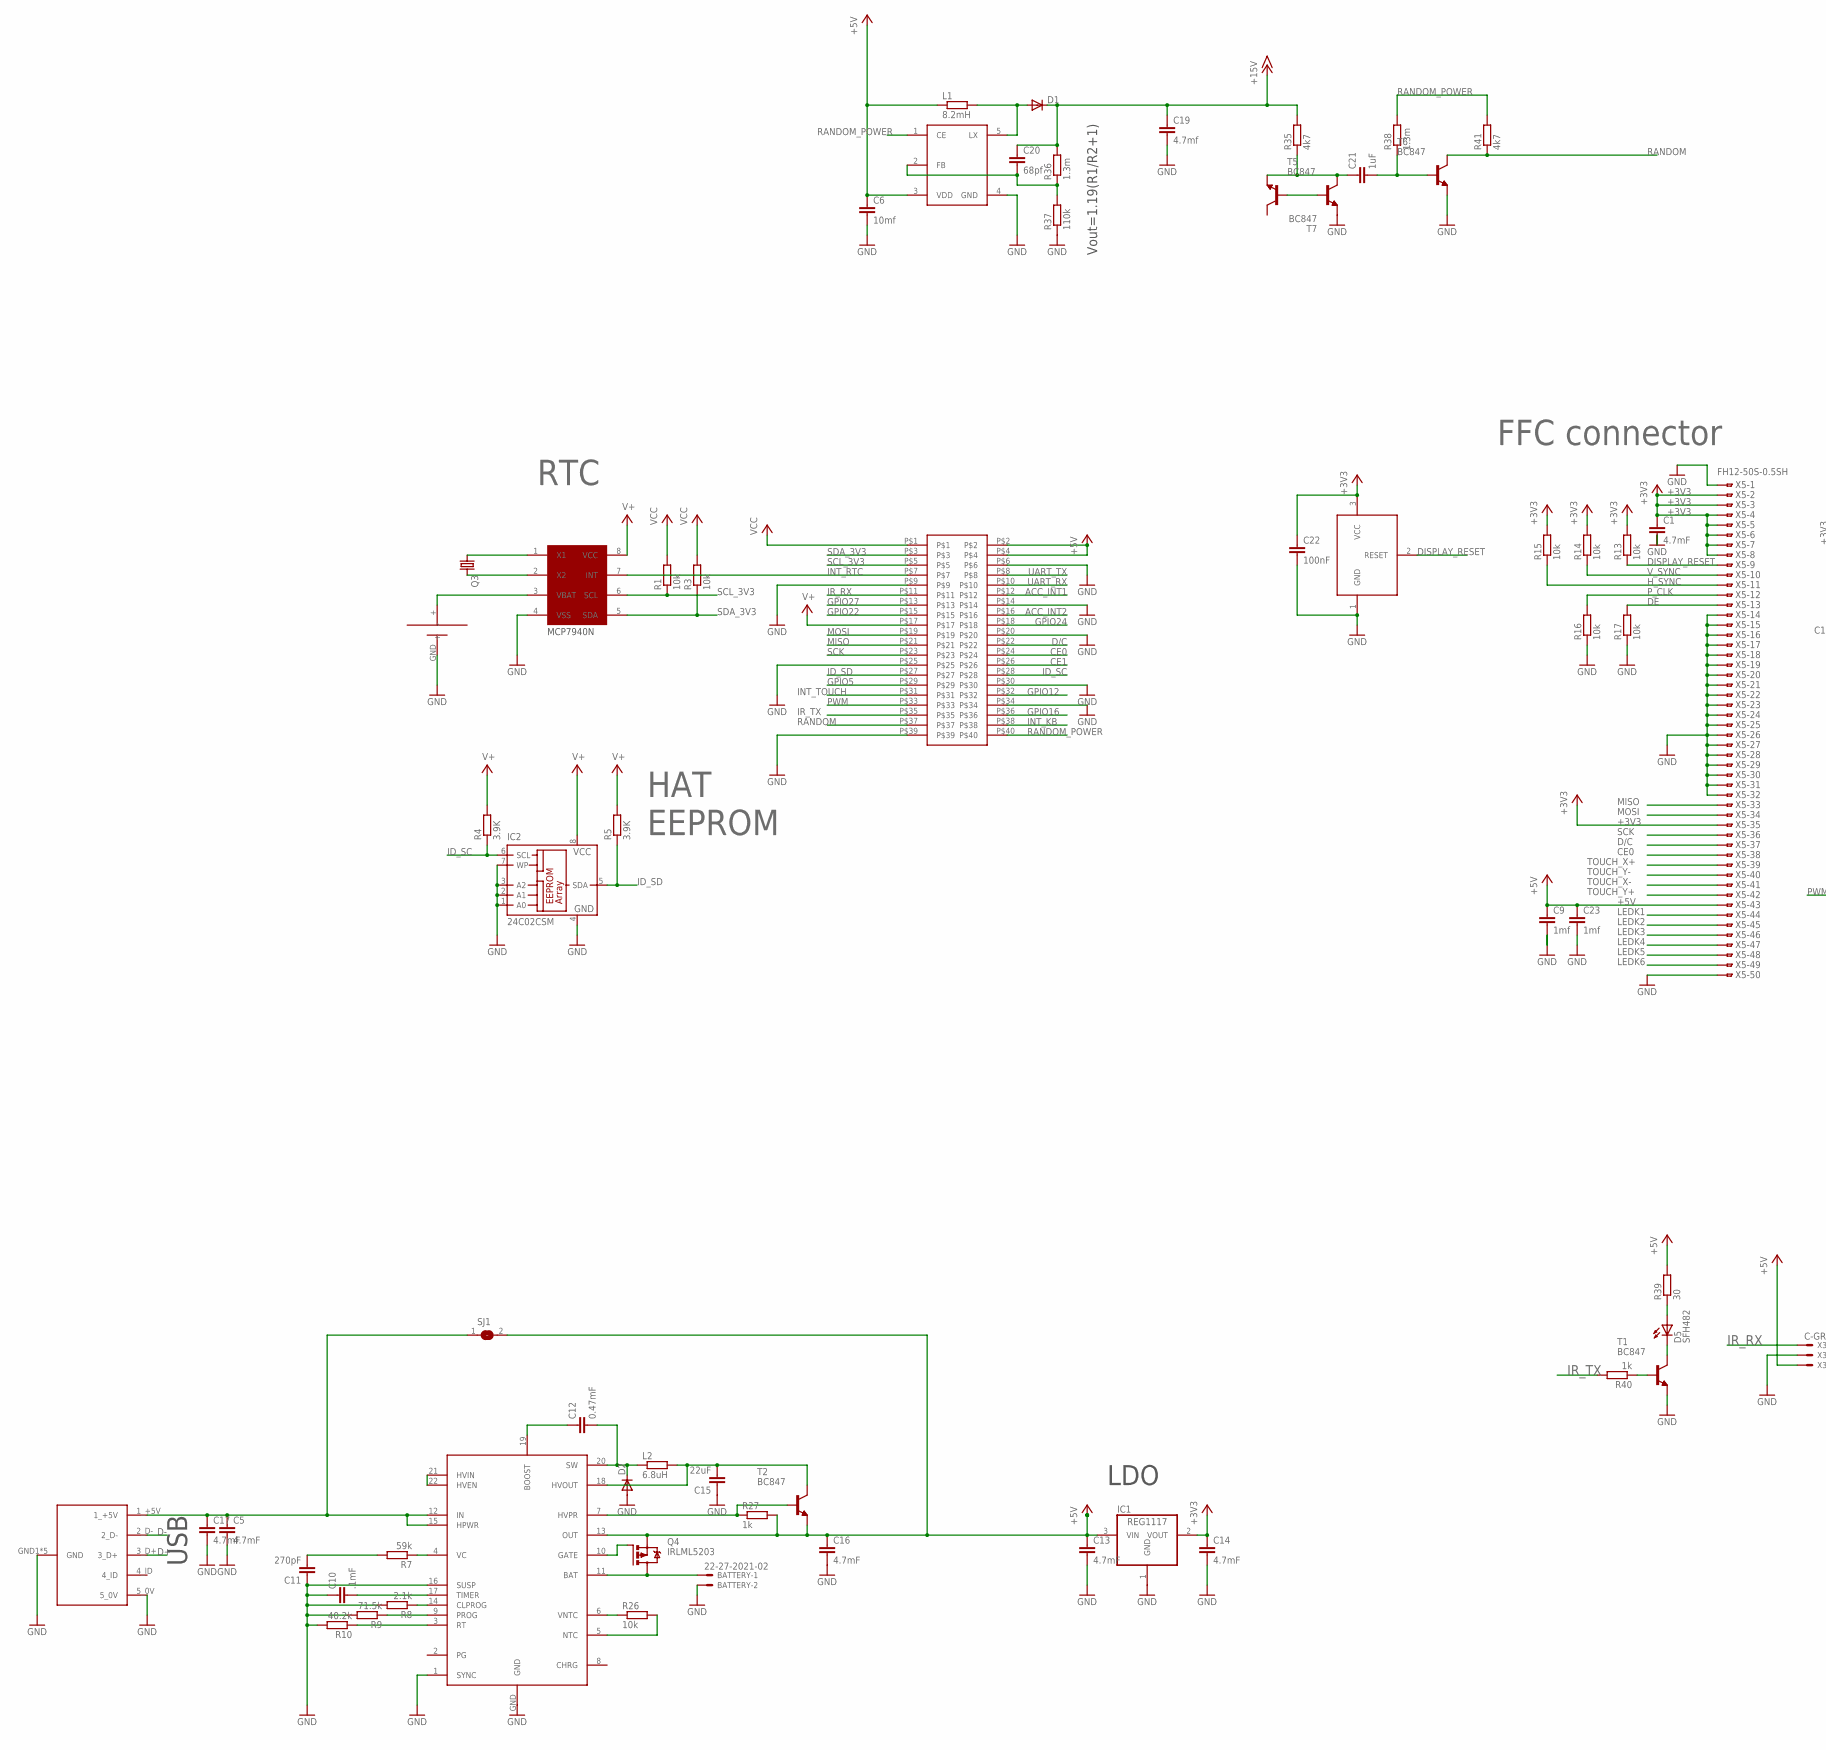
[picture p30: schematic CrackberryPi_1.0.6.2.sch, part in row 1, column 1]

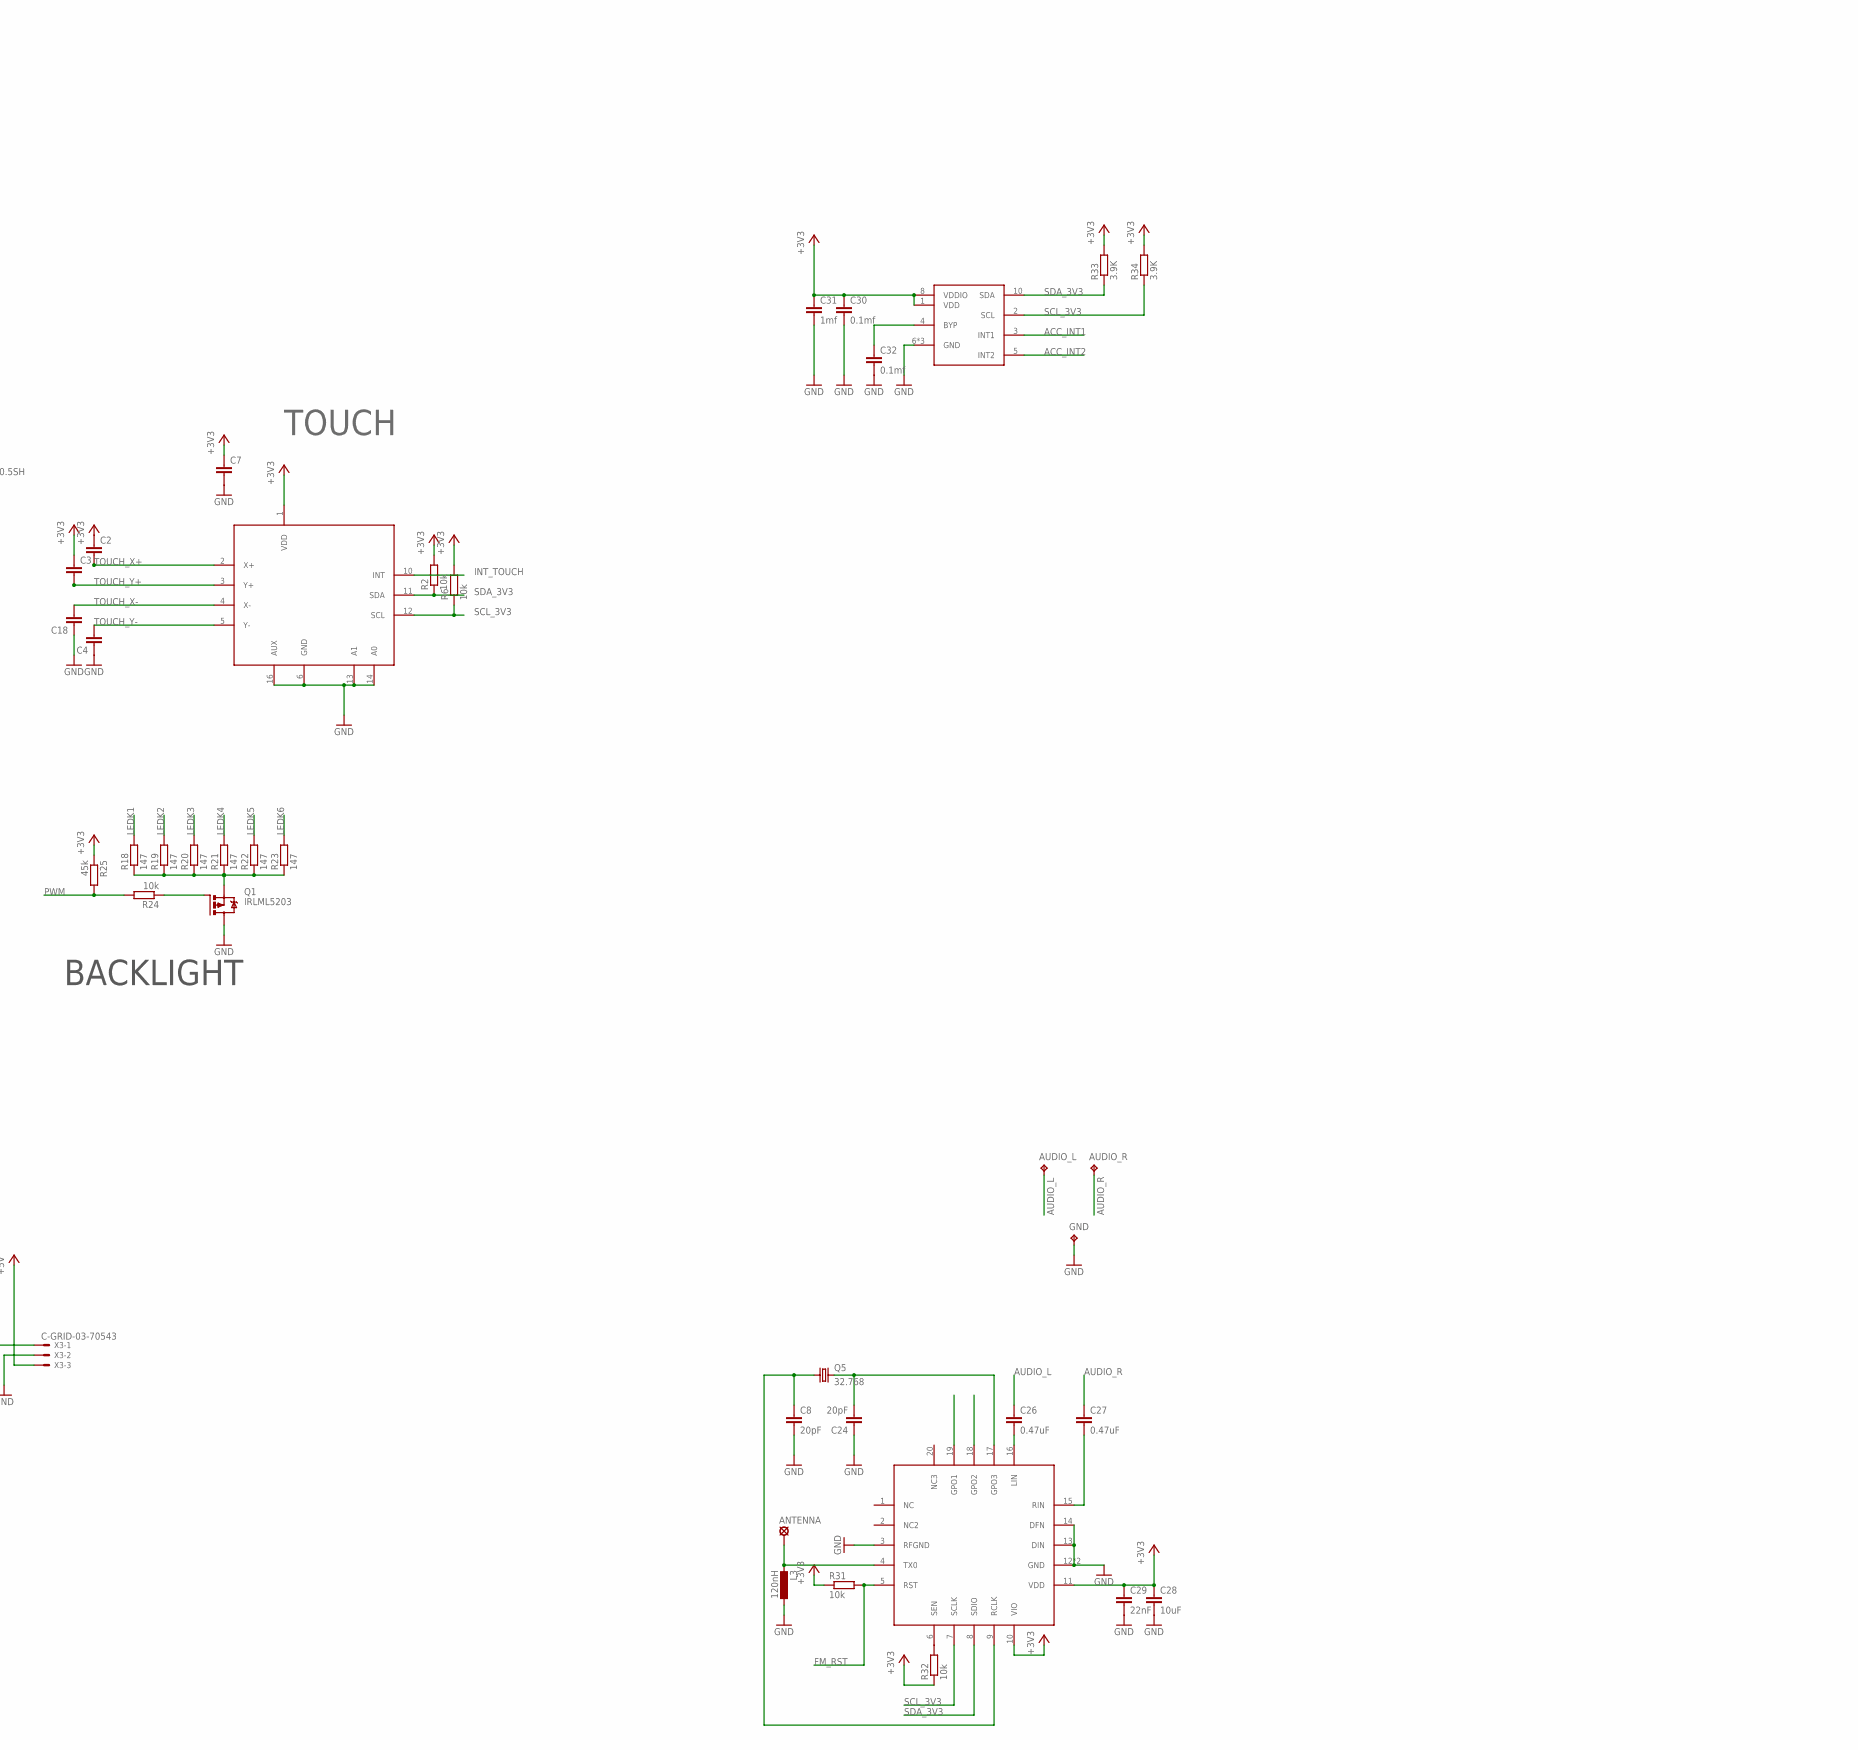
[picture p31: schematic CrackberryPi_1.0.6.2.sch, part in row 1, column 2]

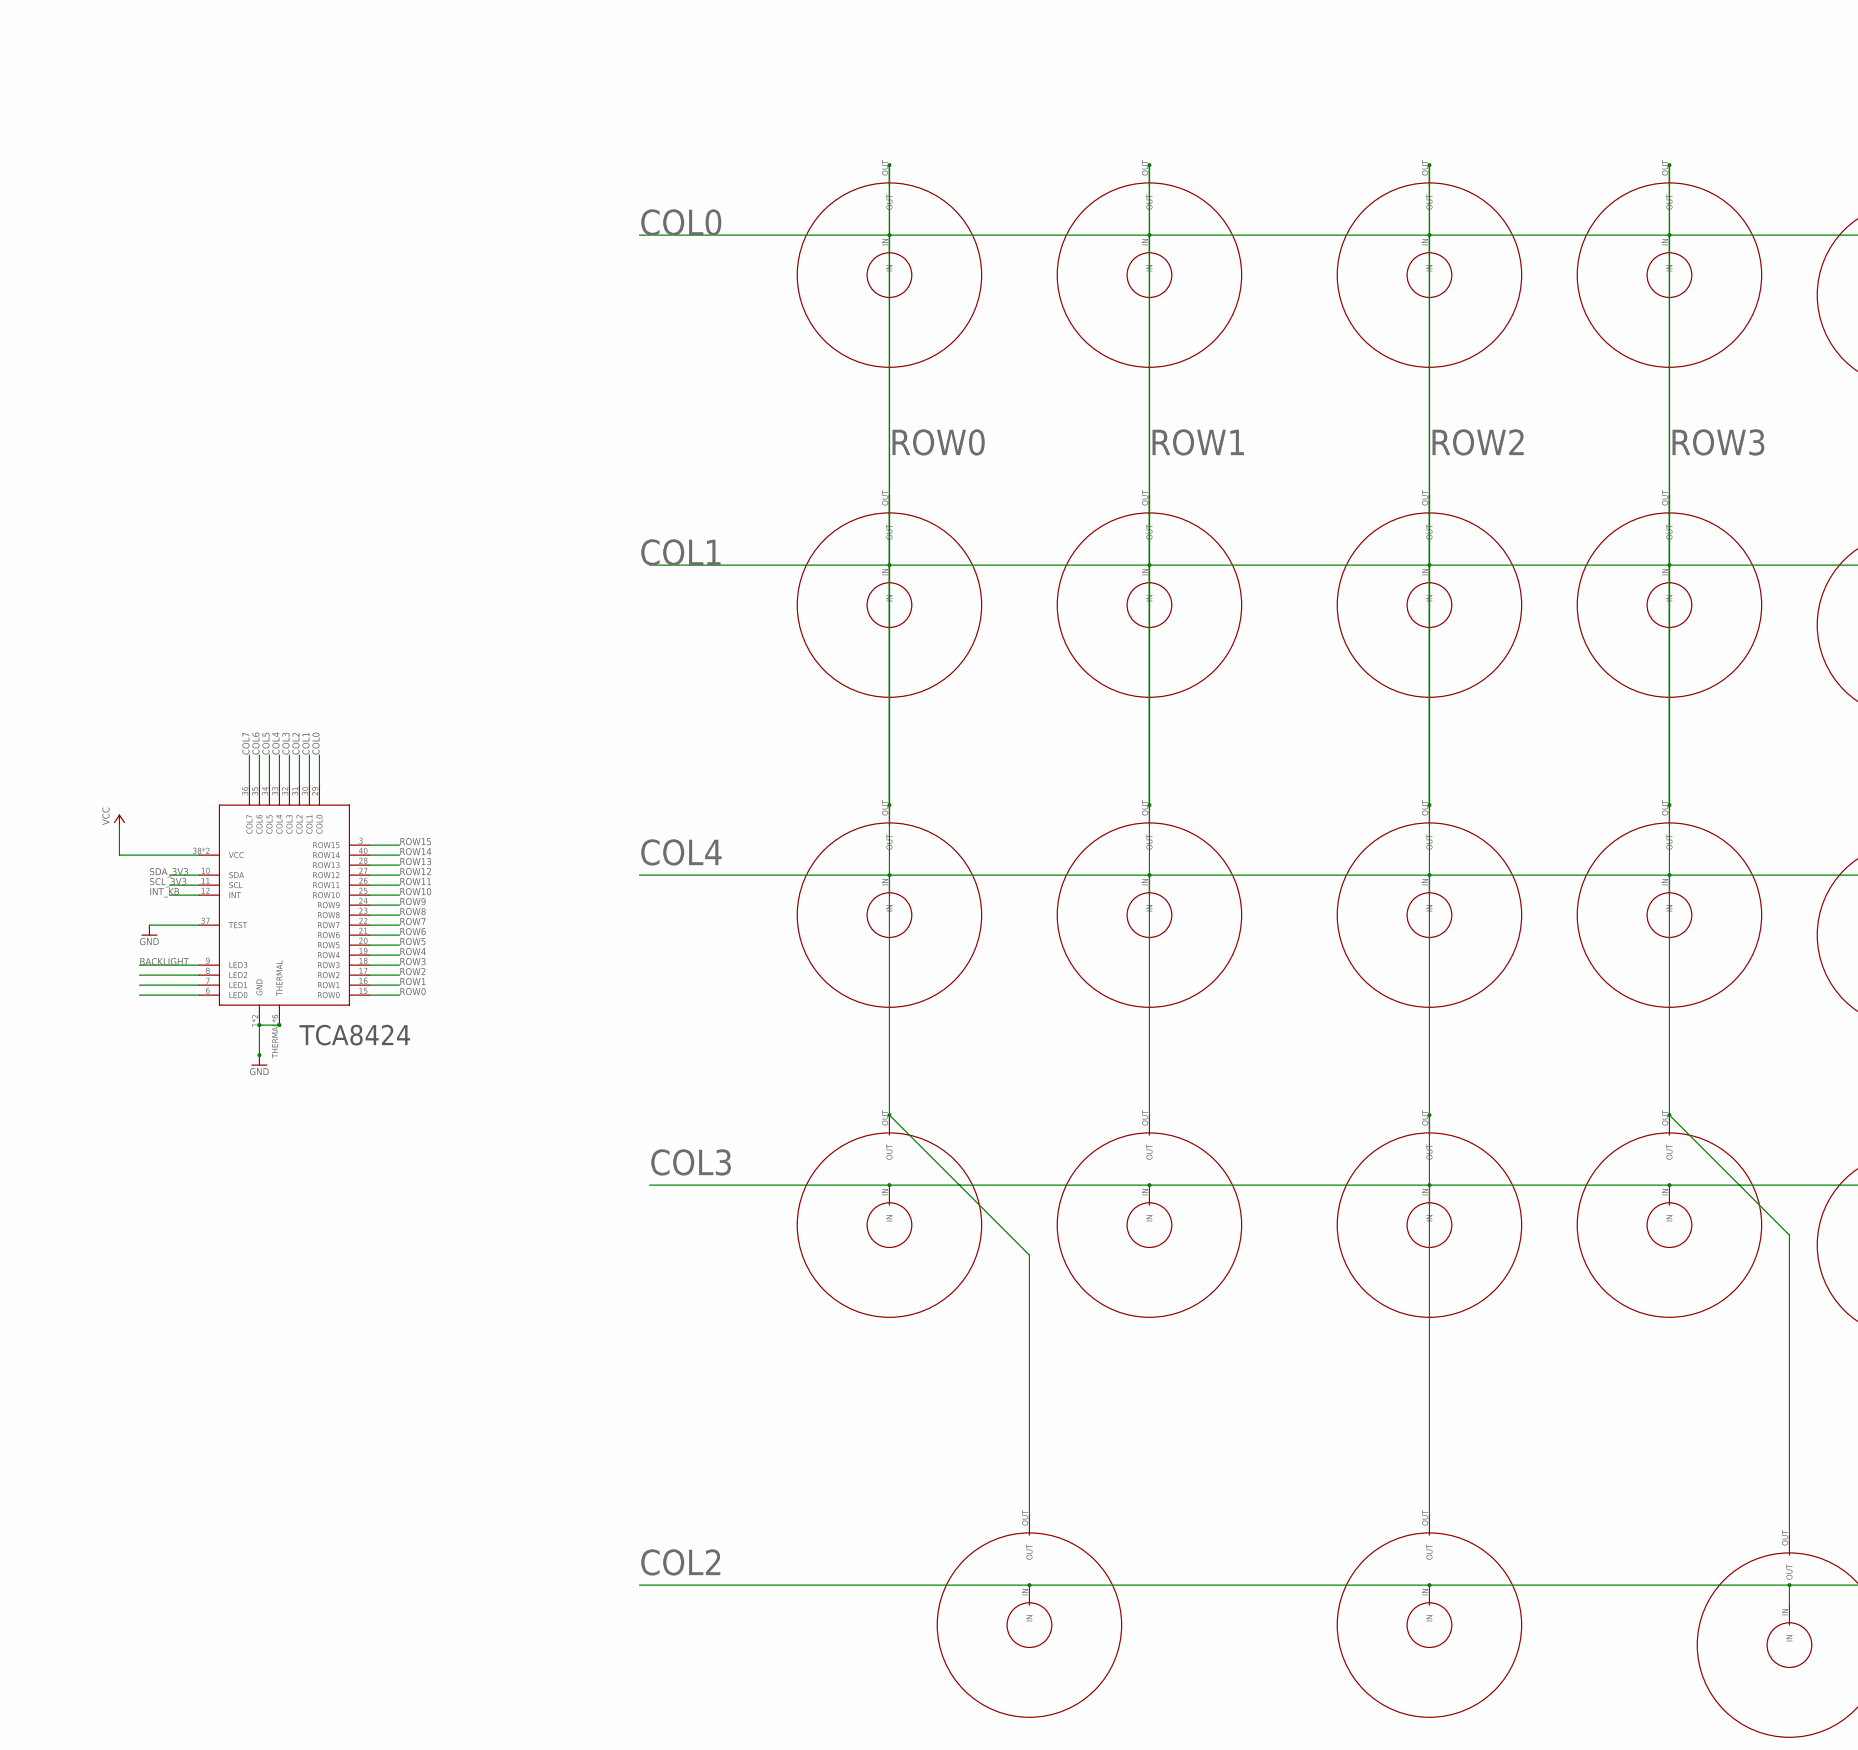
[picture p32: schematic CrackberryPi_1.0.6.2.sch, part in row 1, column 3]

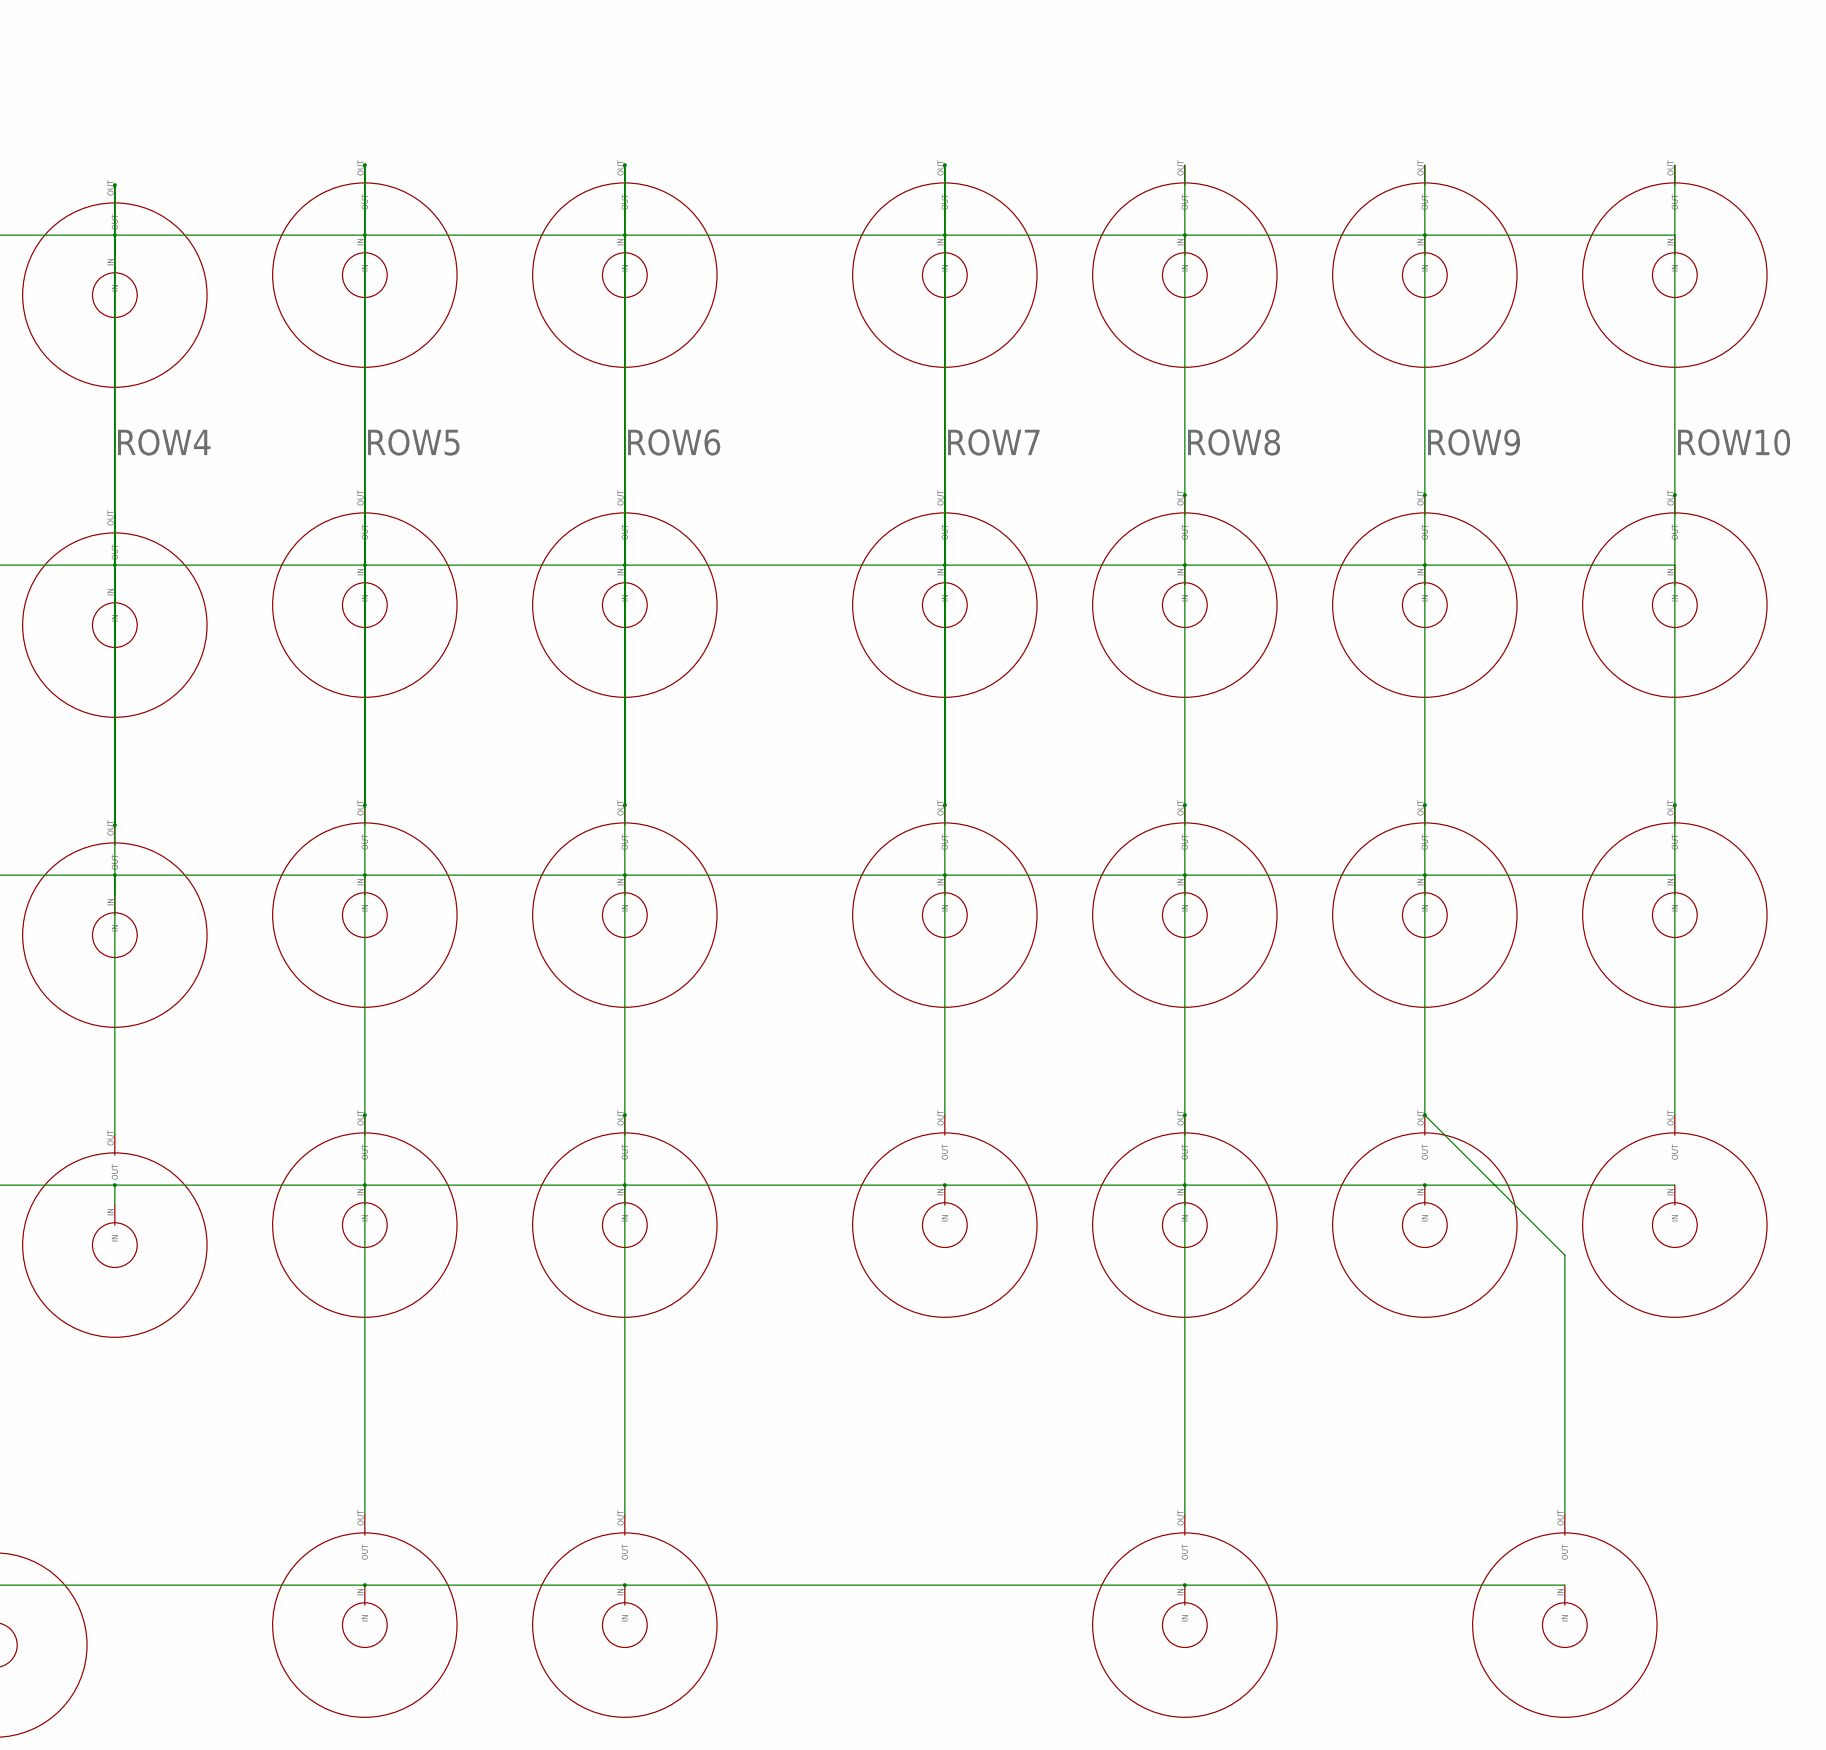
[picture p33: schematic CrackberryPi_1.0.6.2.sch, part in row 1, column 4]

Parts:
1, 2, 3, 4, 5, 6, 7, 8, 9, 10, 11, 12, .: DOME; 4MM
!: DOME; 4MM
(: DOME; 4MM
): DOME; 4MM
,: DOME; 4MM
?: DOME; 4MM
@: DOME; 4MM
A: DOME; 4MM
ANTENNA: LSP10
AUDIO_L: TPB2,54; B2,54
AUDIO_R: TPB2,54; B2,54
B: DOME; 4MM
BATTERY: 22-27-2021-02; 6410-02
C: DOME; 4MM
C1, C5, C13, C14, C16, C17: 4.7mF; C0603
C2, C3, C4, C7, C18: C-EUC0603; C0603
C6: 10mf; C0603
C8, C24: 20pF; C0603
C9, C23, C31: 1mf; C0603
C10: .1mF; C0603
C11: 270pF; C0603
C12: 0.47mF; C0603
C15: 22uF; C1206
C19: 4.7mf; C0603
C20: 68pf; C0603
C21: 1uF; C0603
C22: 100nF; C0603
C26, C27: 0.47uF; C0603
C28: 10uF; C0603
C29: 22nF; C0603
C30, C32: 0.1mf; C0603
D: DOME; 4MM
D1, D2: DIODE-SOD123; SOD123
D5: SFH482
E: DOME; 4MM
F: DOME; 4MM
FN-RIGHT: DOME; 4MM
G: DOME; 4MM
GND: TPB2,54; B2,54
H: DOME; 4MM
I: DOME; 4MM
IC1: REG1117; SOT223
IC2: 24C02CSM; SO-08M
J: DOME; 4MM
K: DOME; 4MM
L: DOME; 4MM
L1: 8.2mH; R0805
L2: 6.8uH; R2010
L3: 120nH; L2012C
M: DOME; 4MM
N: DOME; 4MM
O: DOME; 4MM
P: DOME; 4MM
Q: DOME; 4MM
Q1, Q4: IRLML5203; MICRO3
Q3: CRYSTALMM20SS; MM20SS
Q5: 32.768; MM20SS
R: DOME; 4MM
R1, R2, R3, R6, R13, R14, R15, R16, R17, R24, R26, R31, R32: 10k; R0603
R4, R5, R33, R34: 3.9K; R0603
R7: 59k; R0603
R8: 2.1k; R0603
R9: 71.5k; R0603
R10: 40.2k; R0603
R18, R19, R20, R21, R22, R23: 147; R0603
R25: 45k; R0603
R27, R40: 1k; R0603
R35, R41: 4k7; R0603
R36, R38: 1.3m; R0603
R37: 110k; R0603
R39: 30; R0603
S: DOME; 4MM
SHIFT-RIGHT: DOME; 4MM
SHILFT-LEFT: DOME; 4MM
SJ1: SJ
SPACE1, SPACE2, SPACE3: DOME; 4MM
T: DOME; 4MM
T1, T2, T5, T6, T7: BC847; SOT23
U: DOME; 4MM
U$1: LTC4090; DFN22
U$2: NCP1406; SOT23-5L
U$3: RESETMONITOR; SOT23
U$4: CR1216
U$5: MCP7940N; SO08
U$6: TSC2007; TSSOP16
U$7: TCA8424; QFN40
U$9: MICRO_USB
U$11: HEADER; 20X2
U$12: SI4713; QFN20-3X3
U$13: ACCELLEROMETER; DFN-10_2X2
V: DOME; 4MM
W: DOME; 4MM
X: DOME; 4MM
X3: C-GRID-03-70543; 70543-03
X5: FH12-50S-0.5SH
Y: DOME; 4MM
Z: DOME; 4MM

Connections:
+3V3: C1.1, C2.1, C3.1, C7.1, C14.1, C22.1, C28.1, C29.1, C30.1, C31.1, IC1.2 (VOUT), R2.2, R6.2, R13.2, R14.2, R15.2, R25.1, R31.1, R32.1, R33.2, R34.2, U$3.3 (VCC), U$6.1 (VDD), U$12.10 (VIO), U$12.11 (VDD), U$13.1 (VDD), U$13.8 (VDDIO), X5.2, X5.3, X5.4, X5.5, X5.6, X5.7, X5.8, X5.35
+5V: C6.1, C9.1, C13.1, C16.1, C23.1, IC1.3 (VIN), L1.1, Q4.2 (S), R27.2, R39.2, SJ1.2, T2.2 (E), U$1.13 (OUT), U$2.3 (VDD), U$11.P$2, U$11.P$4, X3.3, X5.43
+15V: C19.1, C20.1, D1.C, R35.2, R36.2
ACC_INT1: U$11.P$12, U$13.3 (INT1)
ACC_INT2: U$11.P$16, U$13.5 (INT2)
AUDIO_L: AUDIO_L.TP, C26.1
AUDIO_R: AUDIO_R.TP, C27.1
BACKLIGHT: U$7.9 (LED3)
BASE: R40.1, T1.1 (B)
BAT: BATTERY.1, Q4.3 (D), U$1.11 (BAT)
BOOST: C12.1, U$1.19 (BOOST)
CE0: U$11.P$24, X5.38
CE1: U$11.P$26
COL0: 1.IN, 2.IN, 3.IN, 4.IN, 5.IN, 6.IN, 7.IN, 8.IN, 9.IN, 10.IN, 11.IN, U$7.29 (COL0)
COL1: 12.IN, E.IN, I.IN, O.IN, P.IN, Q.IN, R.IN, T.IN, U.IN, U$7.30 (COL1), W.IN, Y.IN
COL2: @.IN, FN-RIGHT.IN, SHIFT-RIGHT.IN, SHILFT-LEFT.IN, SPACE1.IN, SPACE2.IN, SPACE3.IN, U$7.31 (COL2)
COL3: !.IN, ,.IN, ..IN, ?.IN, B.IN, C.IN, M.IN, N.IN, U$7.32 (COL3), V.IN, X.IN, Z.IN
COL4: (.IN, ).IN, A.IN, D.IN, F.IN, G.IN, H.IN, J.IN, K.IN, L.IN, S.IN, U$7.33 (COL4)
COL5: U$7.34 (COL5)
COL6: U$7.35 (COL6)
COL7: U$7.36 (COL7)
COLLECTOR: D5.K (C), T1.3 (C)
D+: U$9.3_D+
D-: U$9.2_D-
D/C: U$11.P$22, X5.37
DE: R17.2, X5.13
DISPLAY_RESET: R13.1, U$3.2 (RESET), X5.9
FB: C20.2, R36.1, R37.2, U$2.2 (FB)
FM_RST: R31.2, U$12.5 (RST)
GND: BATTERY.2, C1.2, C4.1, C5.2, C6.2, C7.2, C8.2, C9.2, C10.1, C11.1, C13.2, C14.2, C15.1, C16.2, C17.2, C18.1, C19.2, C22.2, C23.2, C24.1, C28.2, C29.2, C30.2, C31.2, C32.2, D2.A, GND.TP, IC1.1 (GND), IC2.1 (A0), IC2.2 (A1), IC2.3 (A2), IC2.4 (GND), IC2.7 (WP), L3.1, Q1.3 (D), R8.2, R9.2, R10.2, R16.1, R17.1, R37.1, T1.2 (E), T5.2 (E), T6.2 (E), U$1.1 (SYNC), U$1.16 (SUSP), U$1.GND, U$2.4 (GND), U$3.1 (GND), U$4.GND (-), U$5.4 (VSS), U$6.6 (GND), U$6.13 (A1), U$6.14 (A0), U$6.16 (AUX), U$7.1 (GND), U$7.4 (GND), U$7.37 (TEST), U$7.THERMAL, U$7.VIA1 (THERMAL), U$7.VIA2 (THERMAL), U$7.VIA3 (THERMAL), U$7.VIA4 (THERMAL), U$7.VIA5 (THERMAL), U$9.5_0V, U$9.GND1 (GND), U$9.GND2 (GND), U$9.GND5 (GND), U$9.P$1 (GND), U$9.P$7 (GND), U$11.P$6, U$11.P$9, U$11.P$14, U$11.P$20, U$11.P$25, U$11.P$30, U$11.P$34, U$11.P$39, U$12.3 (RFGND), U$12.12 (GND), U$12.13 (DIN), U$12.14 (DFN), U$12.P$1 (GND), U$13.6 (GND), U$13.7 (GND), U$13.9 (GND), X3.2, X5.1, X5.14, X5.15, X5.16, X5.17, X5.18, X5.19, X5.20, X5.21, X5.22, X5.23, X5.24, X5.25, X5.26, X5.27, X5.28, X5.29, X5.30, X5.31, X5.32, X5.50
GPIO5: U$11.P$29
GPIO12: U$11.P$32
GPIO16: U$11.P$36
GPIO22: U$11.P$15
GPIO24: U$11.P$18
GPIO27: U$11.P$13
GPO1: U$12.19 (GPO1)
GPO2: U$12.18 (GPO2)
HVOUT: C15.2, L2.2, T2.3 (C), U$1.18 (HVOUT)
HVPR: R27.1, T2.1 (B), U$1.7 (HVPR)
H_SYNC: R15.1, X5.11
ID_SC: IC2.6 (SCL), R4.1, U$11.P$28
ID_SD: IC2.5 (SDA), R5.1, U$11.P$27
IN: C5.1, C17.1, SJ1.1, U$1.12 (IN), U$1.15 (HPWR), U$9.1_+5V
INT_KB: U$7.12 (INT), U$11.P$38
INT_RTC: U$5.7 (INT), U$11.P$7
INT_TOUCH: U$6.10 (INT), U$11.P$31
IR_RX: U$11.P$11, X3.1
IR_TX: R40.2, U$11.P$35
LEDK1: R18.2, X5.44
LEDK2: R19.2, X5.45
LEDK3: R20.2, X5.46
LEDK4: R21.2, X5.47
LEDK5: R22.2, X5.48
LEDK6: R23.2, X5.49
LX: D1.A, L1.2, U$2.5 (LX)
MISO: U$11.P$21, X5.33
MOSI: U$11.P$19, X5.34
unnamed: Q3.4 (2), U$5.2 (X2)
unnamed: Q3.1, U$5.1 (X1)
unnamed: R9.1, U$1.9 (PROG)
unnamed: R10.1, U$1.3 (RT)
unnamed: R8.1, U$1.14 (CLPROG)
unnamed: R7.1, U$1.4 (VC)
unnamed: C10.2, U$1.17 (TIMER)
unnamed: C11.2, R7.2
unnamed: U$1.21 (HVIN), U$1.22 (HVEN)
unnamed: Q1.2 (S), R18.1, R19.1, R20.1, R21.1, R22.1, R23.1
unnamed: C8.1, Q5.1, U$12.9 (RCLK)
unnamed: T5.1 (B), T7.1 (B)
unnamed: C24.2, Q5.4 (2), U$12.17 (GPO3)
unnamed: Q1.1 (G), R24.1
unnamed: R26.1, U$1.6 (VNTC)
unnamed: C26.2, U$12.16 (LIN)
unnamed: C27.2, U$12.15 (RIN)
unnamed: ANTENNA.MP, L3.2, U$12.4 (TX0)
unnamed: R26.2, U$1.5 (NTC)
unnamed: C21.1, R35.1, T5.3 (C), T7.2 (E)
unnamed: R32.2, U$12.6 (SEN)
unnamed: D5.A, R39.1
unnamed: C32.1, U$13.4 (BYP)
unnamed: C21.2, R38.1, T6.1 (B)
unnamed: Q4.1 (G), U$1.10 (GATE)
PWM: R24.2, R25.2, U$11.P$33
P_CLK: R16.2, X5.12
RANDOM: R41.1, T6.3 (C), U$11.P$37
RANDOM_POWER: R38.2, R41.2, U$2.1 (CE), U$11.P$40
ROW0: 1.OUT, A.OUT, Q.OUT, SHILFT-LEFT.OUT, U$7.15 (ROW0), Z.OUT
ROW1: 2.OUT, S.OUT, U$7.16 (ROW1), W.OUT, X.OUT
ROW2: 3.OUT, C.OUT, D.OUT, E.OUT, SPACE1.OUT, U$7.17 (ROW2)
ROW3: 4.OUT, F.OUT, R.OUT, SPACE2.OUT, U$7.18 (ROW3), V.OUT
ROW4: 5.OUT, B.OUT, G.OUT, T.OUT, U$7.19 (ROW4)
ROW5: 6.OUT, H.OUT, N.OUT, SPACE3.OUT, U$7.20 (ROW5), Y.OUT
ROW6: 7.OUT, J.OUT, M.OUT, SHIFT-RIGHT.OUT, U.OUT, U$7.21 (ROW6)
ROW7: 8.OUT, ?.OUT, I.OUT, K.OUT, U$7.22 (ROW7)
ROW8: 9.OUT, !.OUT, @.OUT, L.OUT, O.OUT, U$7.23 (ROW8)
ROW9: 10.OUT, (.OUT, ,.OUT, FN-RIGHT.OUT, P.OUT, U$7.24 (ROW9)
ROW10: 11.OUT, 12.OUT, ).OUT, ..OUT, U$7.25 (ROW10)
ROW11: U$7.26 (ROW11)
ROW12: U$7.27 (ROW12)
ROW13: U$7.28 (ROW13)
ROW14: U$7.40 (ROW14)
ROW15: U$7.3 (ROW15)
SCK: U$11.P$23, X5.36
SCL_3V3: R1.1, R6.1, R34.1, U$5.6 (SCL), U$6.12 (SCL), U$7.11 (SCL), U$11.P$5, U$12.7 (SCLK), U$13.2 (SCL)
SDA_3V3: R2.1, R3.1, R33.1, U$5.5 (SDA), U$6.11 (SDA), U$7.10 (SDA), U$11.P$3, U$12.8 (SDIO), U$13.10 (SDA)
SW: C12.2, D2.C, L2.1, U$1.20 (SW)
TOUCH_X+: C2.2, U$6.2 (X+), X5.39
TOUCH_X-: C18.2, U$6.4 (X-), X5.41
TOUCH_Y+: C3.2, U$6.3 (Y+), X5.42
TOUCH_Y-: C4.2, U$6.5 (Y-), X5.40
UART_RX: U$11.P$10
UART_TX: U$11.P$8
V+: IC2.8 (VCC), R4.2, R5.2, U$5.8 (VCC), U$11.P$17
VBAT+: U$4.+, U$5.3 (VBAT)
VCC: R1.2, R3.2, U$7.38 (VCC), U$7.39 (VCC), U$11.P$1
V_SYNC: R14.1, X5.10

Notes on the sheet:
RTC
HAT EEPROM
TOUCH
FFC connector
BACKLIGHT
MCP7940N
USB
LDO
Vout=1.19(R1/R2+1)
TCA8424

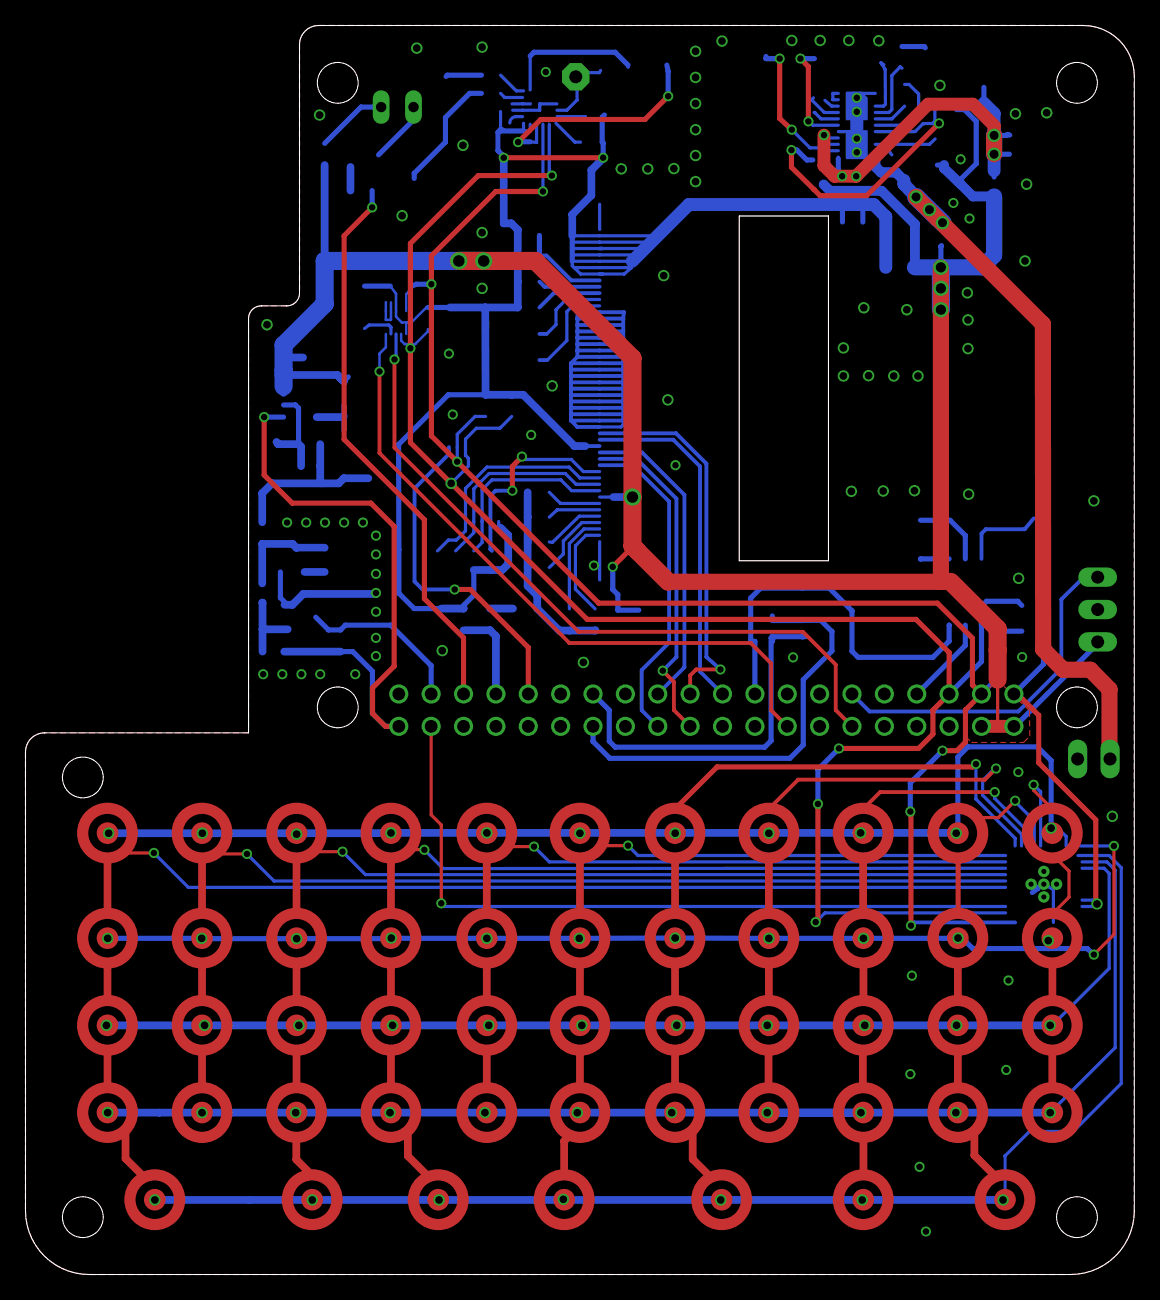
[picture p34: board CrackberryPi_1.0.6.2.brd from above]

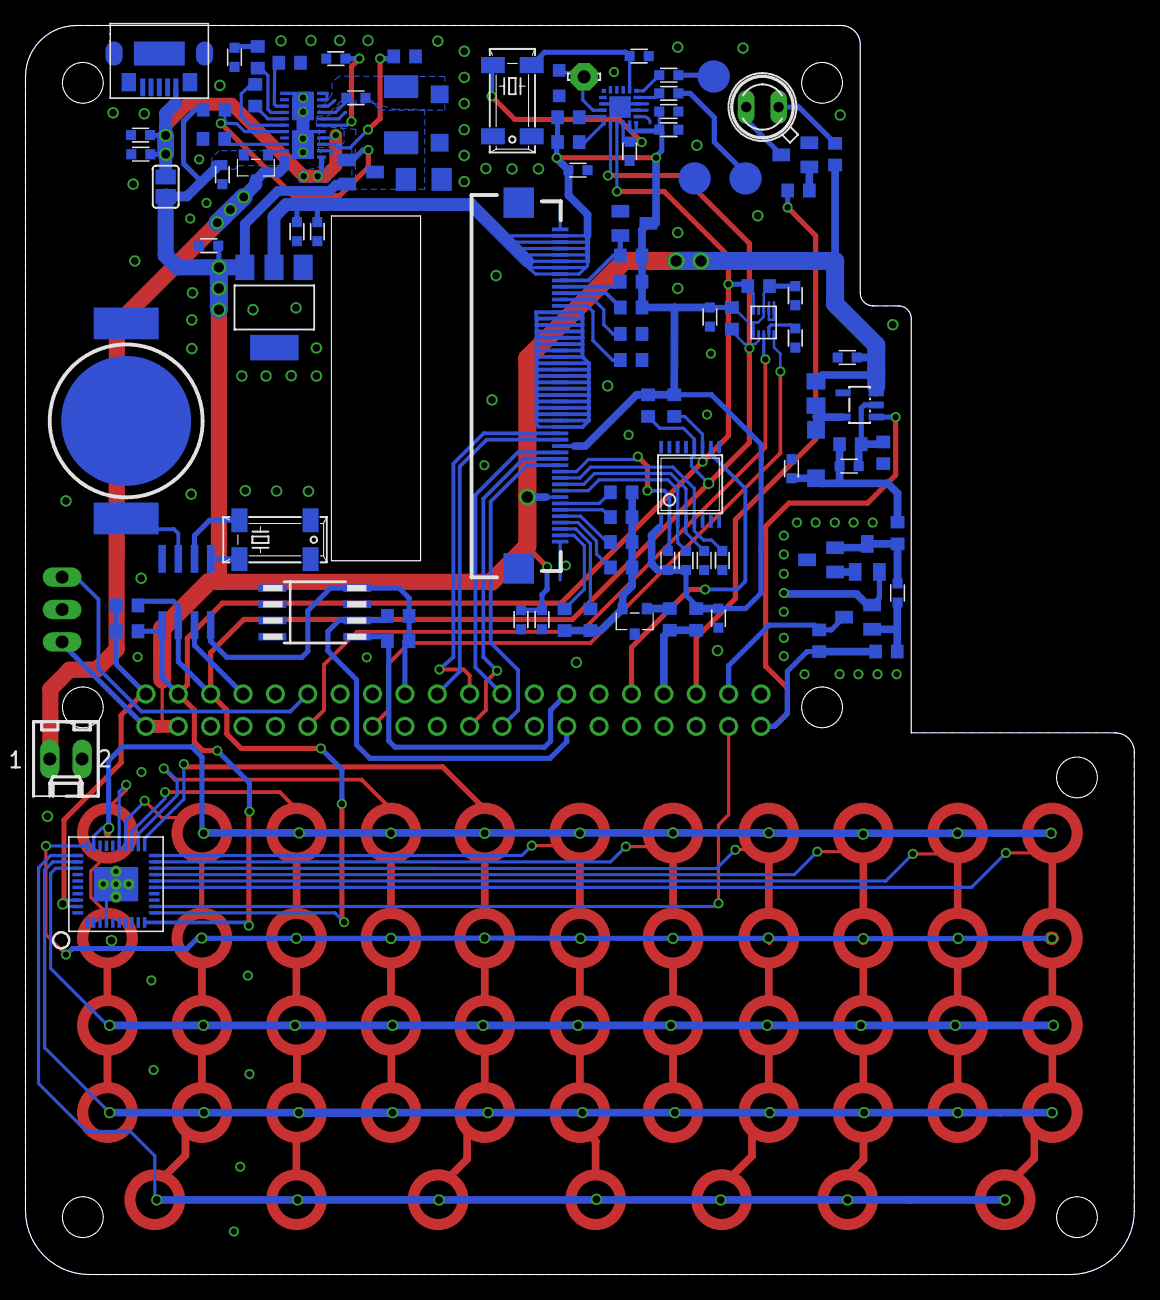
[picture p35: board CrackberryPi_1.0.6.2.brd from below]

Board: 2 copper layers, 87.0 x 98.0 mm, 154 parts (102 on the bottom side), 95 nets.

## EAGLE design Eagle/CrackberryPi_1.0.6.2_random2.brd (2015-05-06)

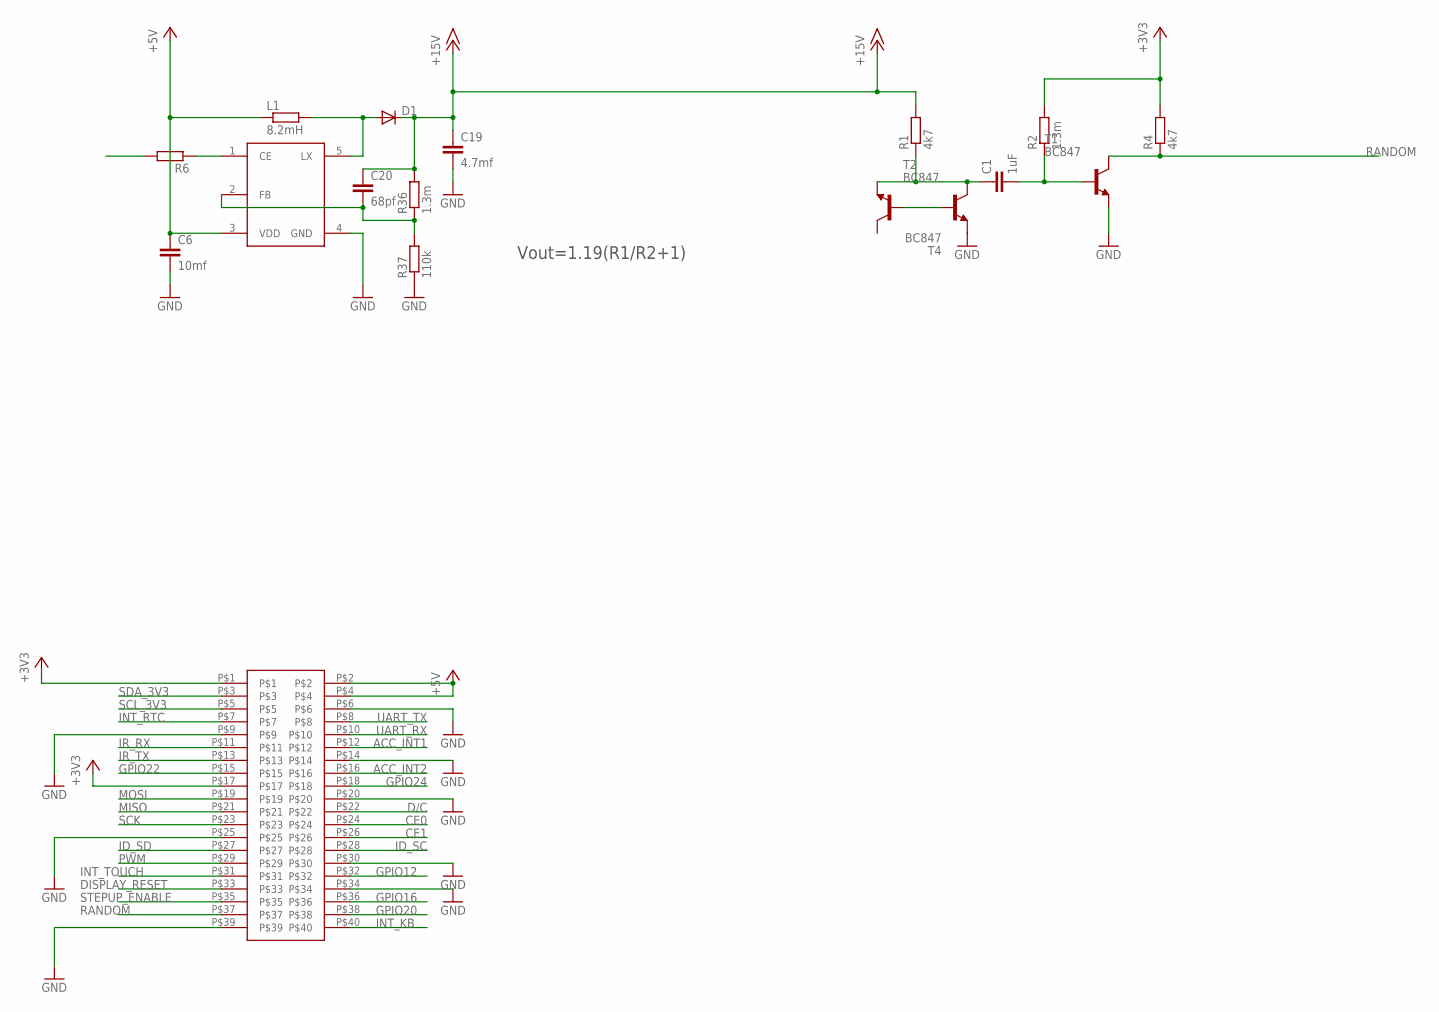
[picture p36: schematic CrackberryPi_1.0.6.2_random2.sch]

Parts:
C1: 1uF; C0603
C6: 10mf; C0603
C19: 4.7mf; C0603
C20: 68pf; C0603
D1: DIODE-SOD123; SOD123
L1: 8.2mH; R1210
R1, R4: 4k7; R0603
R2, R36: 1.3m; R0603
R6: R-EU_R1210; R1210
R37: 110k; R0603
T1, T2, T4: BC847; SOT23
U$2: NCP1406; SOT23-5L
U$11: HEADER; 20X2

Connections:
+3V3: R2.2, R4.2, U$11.P$1, U$11.P$17
+5V: C6.1, L1.1, U$2.3 (VDD), U$11.P$2, U$11.P$4
+15V: C19.1, C20.1, D1.C, R1.2, R36.2
ACC_INT1: U$11.P$12
ACC_INT2: U$11.P$16
CE0: U$11.P$24
CE1: U$11.P$26
D/C: U$11.P$22
DISPLAY_RESET: U$11.P$33
FB: C20.2, R36.1, R37.2, U$2.2 (FB)
GND: C6.2, C19.2, R37.1, T1.2 (E), T2.2 (E), U$2.4 (GND), U$11.P$6, U$11.P$9, U$11.P$14, U$11.P$20, U$11.P$25, U$11.P$30, U$11.P$34, U$11.P$39
GPIO12: U$11.P$32
GPIO16: U$11.P$36
GPIO20: U$11.P$38
GPIO22: U$11.P$15
GPIO24: U$11.P$18
ID_SC: U$11.P$28
ID_SD: U$11.P$27
INT_KB: U$11.P$40
INT_RTC: U$11.P$7
INT_TOUCH: U$11.P$31
IR_RX: U$11.P$11
IR_TX: U$11.P$13
LX: D1.A, L1.2, U$2.5 (LX)
MISO: U$11.P$21
MOSI: U$11.P$19
unnamed: R6.1, U$2.1 (CE)
unnamed: T2.1 (B), T4.1 (B)
unnamed: C1.1, R1.1, T2.3 (C), T4.2 (E)
unnamed: C1.2, R2.1, T1.1 (B)
PWM: U$11.P$29
RANDOM: R4.1, T1.3 (C), U$11.P$37
SCK: U$11.P$23
SCL_3V3: U$11.P$5
SDA_3V3: U$11.P$3
STEPUP_ENABLE: R6.2, U$11.P$35
UART_RX: U$11.P$10
UART_TX: U$11.P$8

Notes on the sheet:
Vout=1.19(R1/R2+1)

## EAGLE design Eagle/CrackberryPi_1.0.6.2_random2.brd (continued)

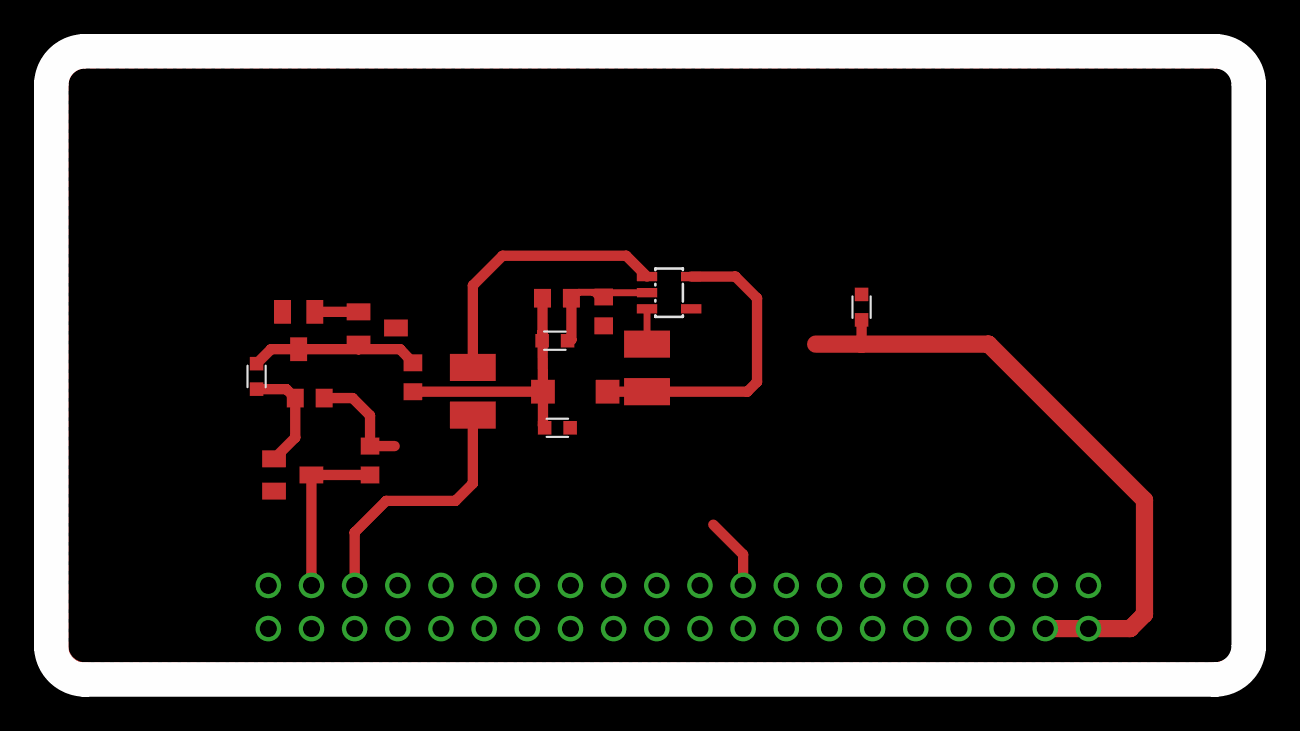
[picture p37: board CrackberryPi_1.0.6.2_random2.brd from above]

Board: 2 copper layers, 70.5 x 37.0 mm, 17 parts (0 on the bottom side), 12 nets.

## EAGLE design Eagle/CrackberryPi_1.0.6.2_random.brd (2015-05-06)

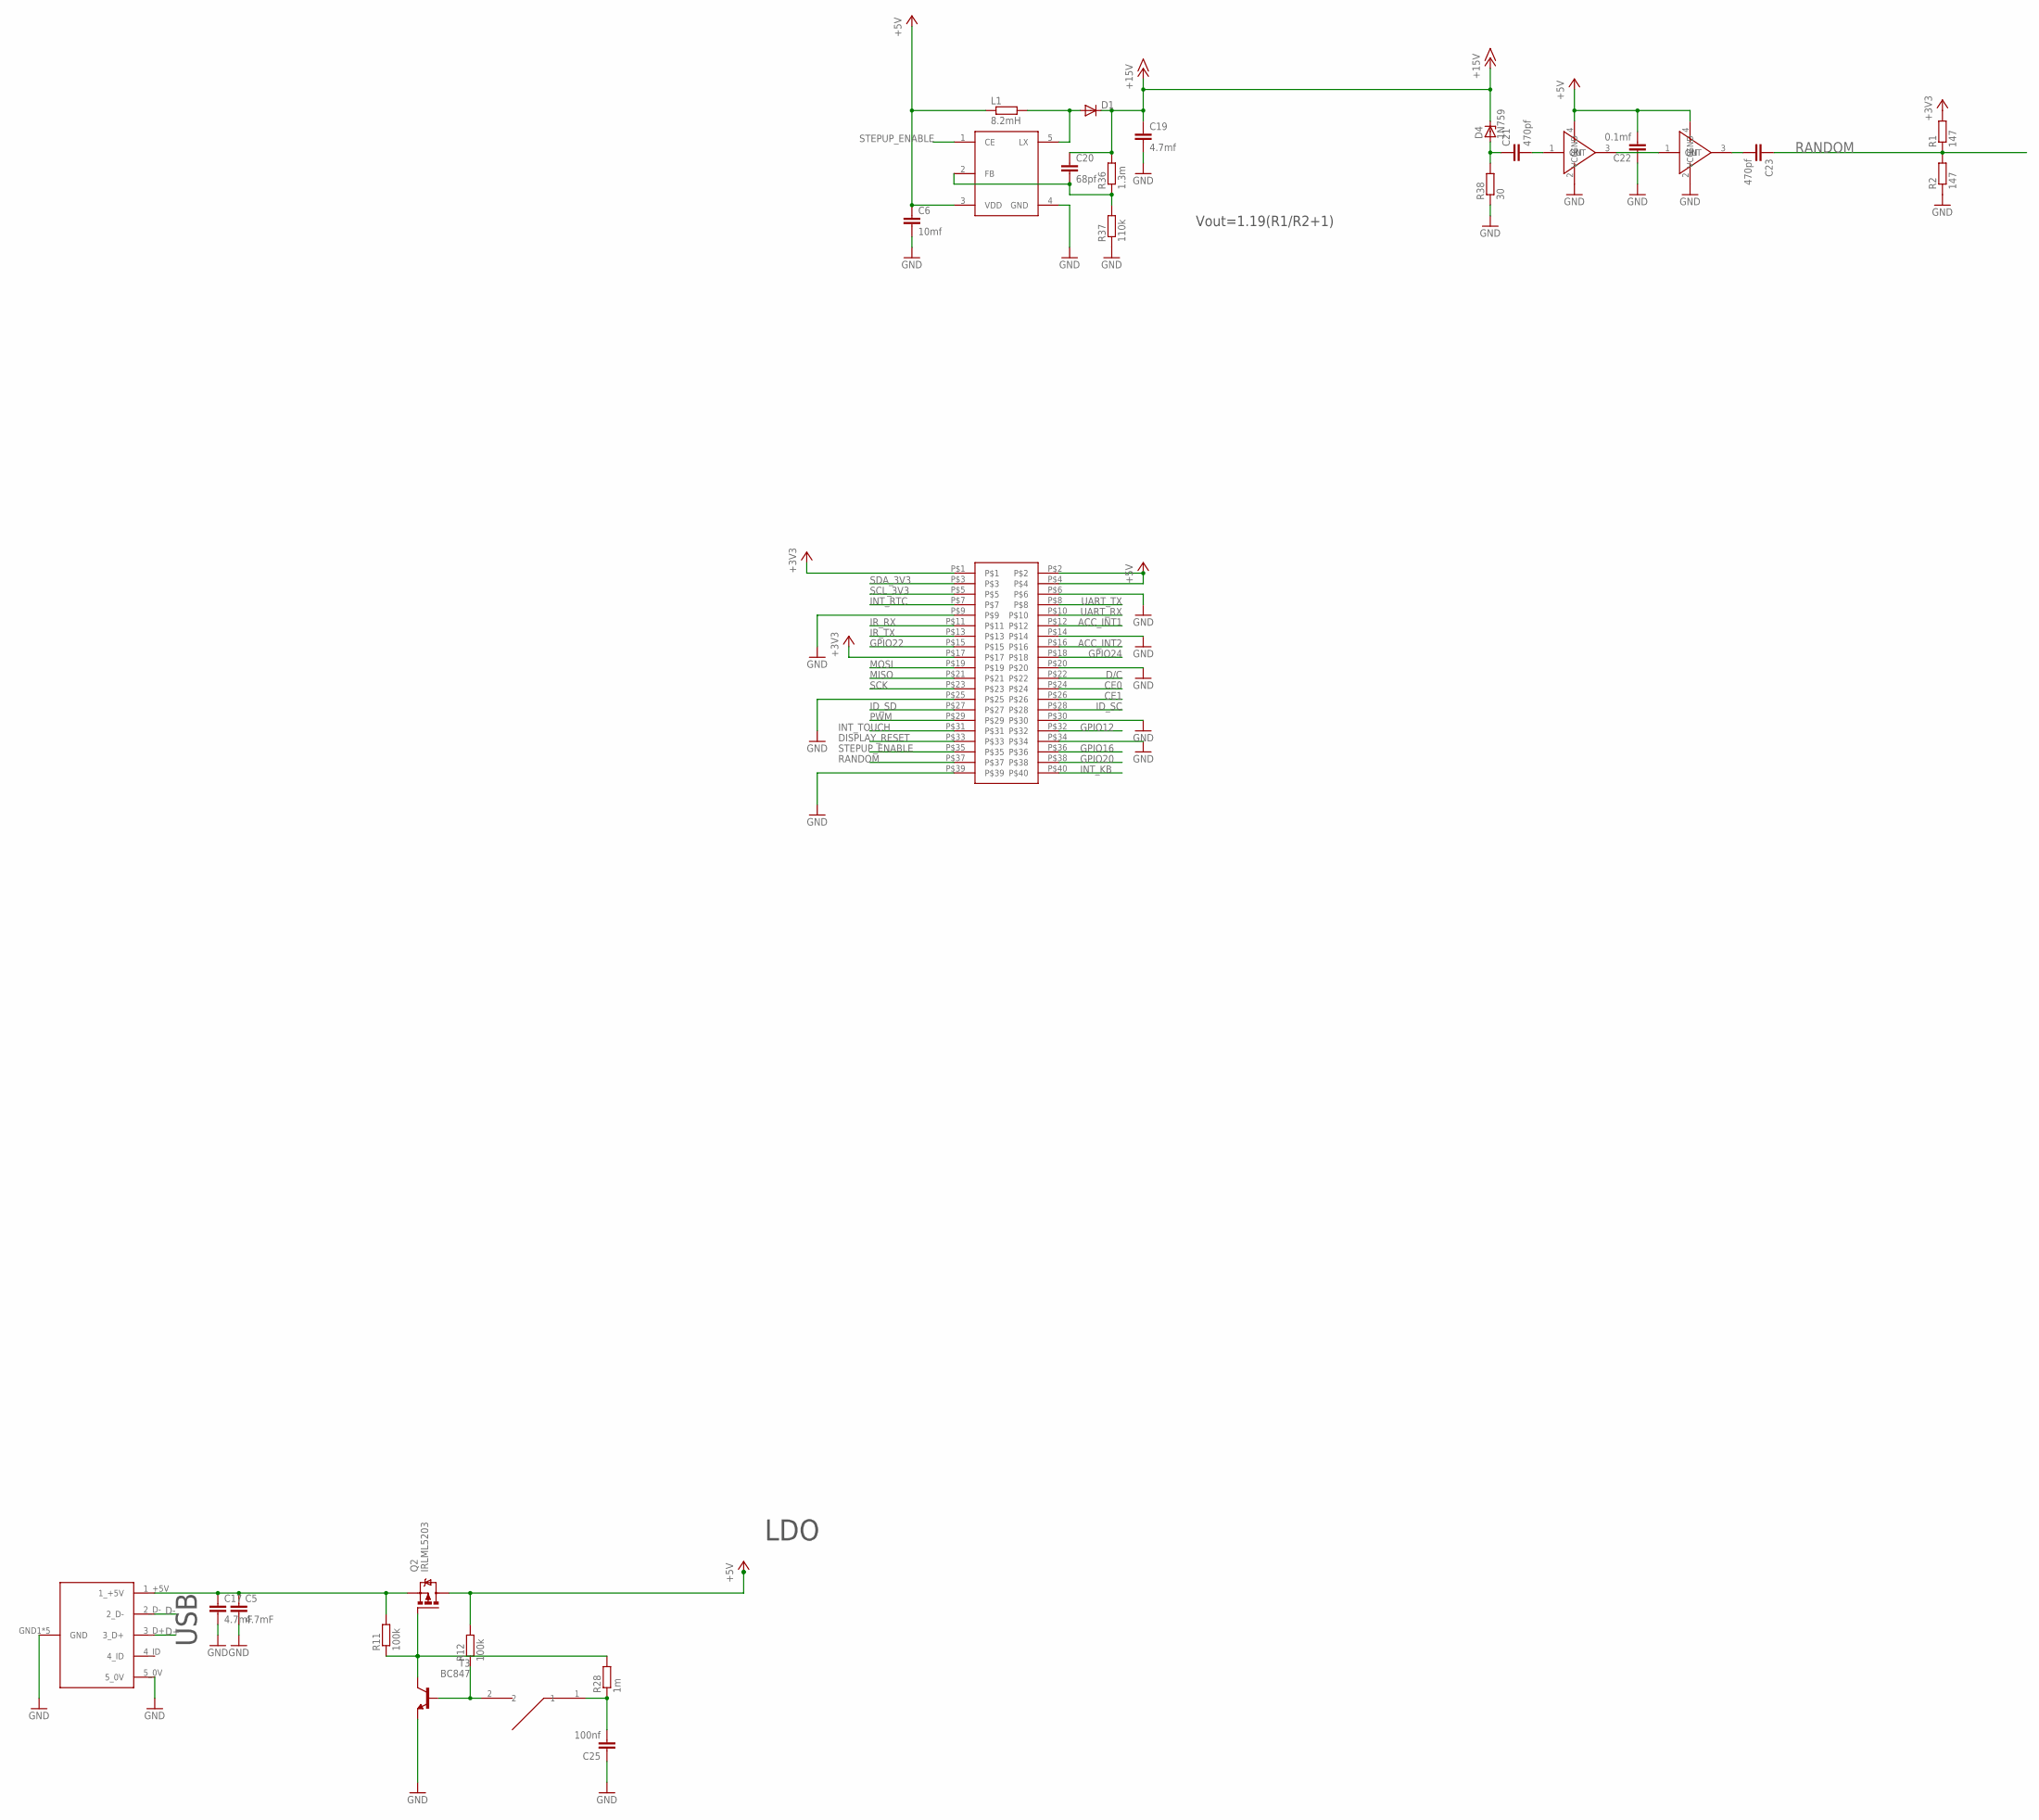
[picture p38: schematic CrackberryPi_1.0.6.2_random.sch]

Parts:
C5, C17: 4.7mF; C0603
C6: 10mf; C0603
C19: 4.7mf; C0603
C20: 68pf; C0603
C21, C23: 470pf; C0603
C22: 0.1mf; C0603
C25: 100nf; C0603
D1: DIODE-SOD123; SOD123
D4: 1N759; SOD80C
L1: 8.2mH; R1210
Q2: IRLML5203; MICRO3
R1, R2: 147; R0603
R11, R12: 100k; R0603
R28: 1m; R0603
R36: 1.3m; R0603
R37: 110k; R0603
R38: 30; R0603
T3: BC847; SOT23
U$2: NCP1406; SOT23-5L
U$3, U$10: MAX2650; SOT143-W
U$8: MOMSWITCH
U$9: MICRO_USB
U$11: HEADER; 20X2

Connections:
+3V3: R1.2, U$11.P$1, U$11.P$17
+5V: C6.1, C22.2, L1.1, Q2.3 (D), R12.2, U$2.3 (VDD), U$3.4 (VCC), U$10.4 (VCC), U$11.P$2, U$11.P$4
+15V: C19.1, C20.1, D1.C, D4.C, R36.2
ACC_INT1: U$11.P$12
ACC_INT2: U$11.P$16
CE0: U$11.P$24
CE1: U$11.P$26
D+: U$9.3_D+
D-: U$9.2_D-
D/C: U$11.P$22
DISPLAY_RESET: U$11.P$33
FB: C20.2, R36.1, R37.2, U$2.2 (FB)
GATE: Q2.1 (G), R11.1, R28.2, T3.3 (C)
GND: C5.2, C6.2, C17.2, C19.2, C22.1, C25.1, R2.1, R37.1, R38.1, T3.2 (E), U$2.4 (GND), U$3.2 (GND), U$9.5_0V, U$9.GND1 (GND), U$9.GND2 (GND), U$9.GND5 (GND), U$9.P$1 (GND), U$9.P$7 (GND), U$10.2 (GND), U$11.P$6, U$11.P$9, U$11.P$14, U$11.P$20, U$11.P$25, U$11.P$30, U$11.P$34, U$11.P$39
GPIO12: U$11.P$32
GPIO16: U$11.P$36
GPIO20: U$11.P$38
GPIO22: U$11.P$15
GPIO24: U$11.P$18
ID_SC: U$11.P$28
ID_SD: U$11.P$27
INT_KB: U$11.P$40
INT_RTC: U$11.P$7
INT_TOUCH: U$11.P$31
IN_1: C21.2, U$3.1 (IN)
IR_RX: U$11.P$11
IR_TX: U$11.P$13
LX: D1.A, L1.2, U$2.5 (LX)
MISO: U$11.P$21
MOSI: U$11.P$19
unnamed: C5.1, C17.1, Q2.2 (S), R11.2, U$9.1_+5V
unnamed: C21.1, D4.A, R38.2
unnamed: R12.1, T3.1 (B), U$8.2
unnamed: C25.2, R28.1, U$8.1
OUT1_IN2: U$3.3 (OUT), U$10.1 (IN)
OUT2: C23.2, U$10.3 (OUT)
PWM: U$11.P$29
RANDOM: C23.1, R1.1, R2.2, U$11.P$37
SCK: U$11.P$23
SCL_3V3: U$11.P$5
SDA_3V3: U$11.P$3
STEPUP_ENABLE: U$2.1 (CE), U$11.P$35
UART_RX: U$11.P$10
UART_TX: U$11.P$8

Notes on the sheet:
USB
LDO
Vout=1.19(R1/R2+1)

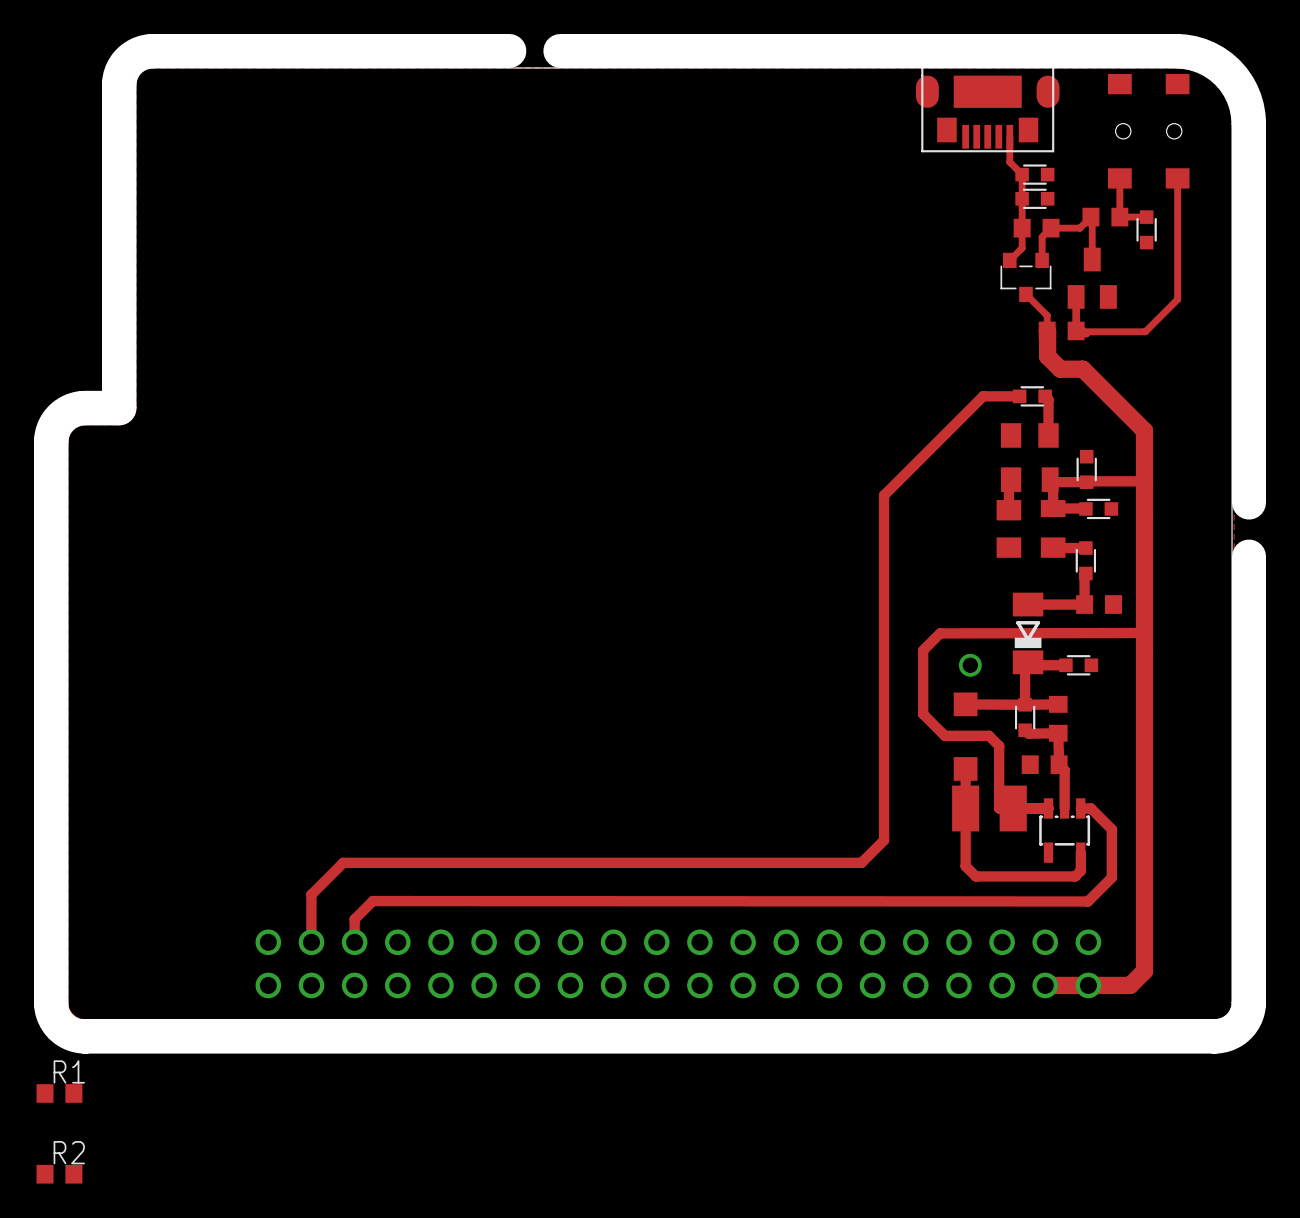
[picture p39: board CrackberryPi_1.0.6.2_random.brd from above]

Board: 2 copper layers, 70.5 x 58.0 mm, 28 parts (0 on the bottom side), 16 nets.

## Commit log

2015-02-19 info on power circuit
2015-02-19 more info on power
2015-02-19 Added basic-sketch in SketchUp format
    [basic-sketch.skp]
2015-02-19 PCB files
    [CrackberryPi.brd, CrackberryPi.sch]
2015-02-19 Battery changes
2015-02-19 Updated sketchup for battery size
    [basic-sketch.skp]
2015-02-20 scherm en touchscreen bestanden en info
    [CrackberryPi.brd, CrackberryPi.sch]
2015-02-20 charging circuit
2015-02-21 screen info
    [CrackberryPi.brd, CrackberryPi.sch]
2015-02-21 screen circuitry picture
2015-02-21 eeprom pin-out check
2015-02-21 part selection
    [CrackberryPi.brd, CrackberryPi.sch]
2015-02-25 pcb development
    [CrackberryPi.brd, CrackberryPi.sch]
2015-03-08 finalizing pcb first proto
    schematics, library parts and gerber rar
    [CrackberryPi.brd, CrackberryPi.sch]
2015-03-11 Revert "CAD designing casing"
    This reverts commit d44902fa8a798b026d4c9fe41ac44cd0e8bc14a0.
    Conflicts:
    CAD/Assembly.SLDASM
    CAD/Backup of Assembly.SLDASM
    CAD/Backup of Casing.SLDPRT
    CAD/BlackBox.PDF
    CAD/Casing.SLDPRT
    CAD/Casing.STL
    More CAD work
    CAD designing casing
    [Assembly.SLDASM, Backup of Assembly.SLDASM, Backup of Casing.SLDPRT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]
2015-03-19 Added schematic png
2015-03-22 work on casing and pcb1.0.2
    [Assembly.SLDASM, Casing.SLDPRT, CrackberryPi_1.0.2.brd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]
2015-03-22 documentatie pcb
    [CrackberryPi_1.0.2.brd]
2015-03-30 pictures, pcb advancements
    [Casing_1.0.2.SLDPRT, Casing_1.0.2.STL, CrackberryPi_1.0.2.brd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]
2015-03-30 charger change
2015-03-30 fm transmitter
    [CrackberryPi_1.0.4.sch]
2015-03-30 BOM en IR
    [BOM.xlsx, CrackberryPi_1.0.4.brd, CrackberryPi_1.0.4.sch]
2015-04-05 screen documentation
    [BOM.xlsx, CrackberryPi_1.0.4.brd, CrackberryPi_1.0.4.sch]
2015-04-28 lots of pcb progress and iterations
    [Backup of Casing_1.0.2.SLDPRT, Backup of Casing_1.1.1.SLDPRT, Casing_1.0.2.SLDPRT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]
2015-05-06 testing progress
    [CrackberryPi_1.0.6.2.brd, CrackberryPi_1.0.6.2.sch, CrackberryPi_1.0.6.2_ir.brd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]
2015-05-19 lots of updates
    [Backup of Casing_1.2.SLDPRT, Casing_1.2.SLDPRT, Casing_1.2.STL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]
